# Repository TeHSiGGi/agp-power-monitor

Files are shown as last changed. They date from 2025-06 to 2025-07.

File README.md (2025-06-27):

# AGP Power Monitor

The APM is a monitoring tool to determine the exact power consumption of an AGP Graphics Card.
It measures both power provided by the AGP slot as well as through external power sources via: 

- 6 pin Mini-Fit Jr. from Molex (PCIe Power) 
- 4 Pin AMP Mate-n-Lok 1-480424-0 (mostly known as Molex connector, though it isn't one).

## Hardware

At the heart of APM is a custom AGP Riser card which consists mainly of an STM32F103C8T6 and three INA3221 power monitors. 

It measures the voltages and currents of the AGP slot as well as of external power providers. Additionally there are two alternative inputs which can be used to measure any user-chosen external power rail as long as it is within specification.

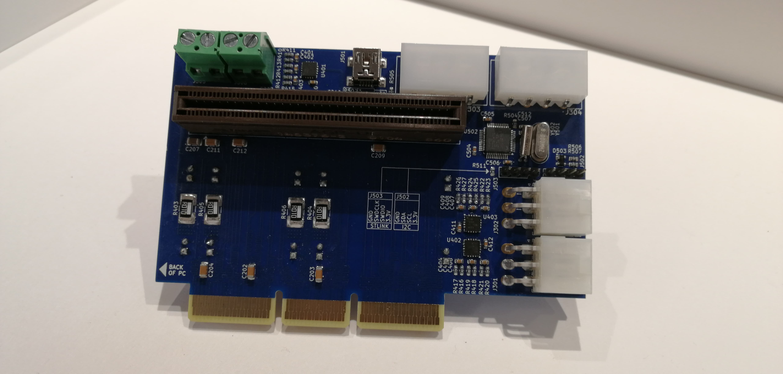
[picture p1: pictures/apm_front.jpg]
APM front

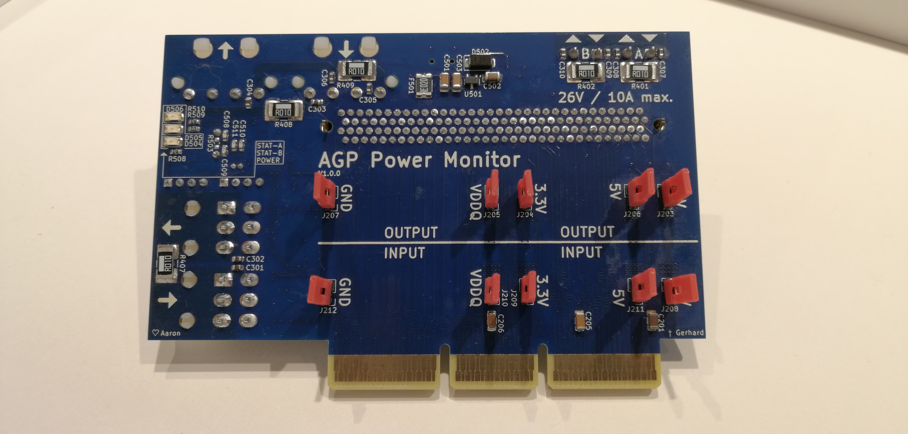
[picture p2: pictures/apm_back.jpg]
APM back


### Power Rails

The following power rails are being measured by the APM.

| Interface | Rail |
| -- | -- |
| AGP slot | 12V |
| AGP slot | 5V |
| AGP slot | 3.3V |
| AGP slot | VDDQ |
| External power | 12V (6Pin) |
| External power | 12V (4Pin) |
| External power | 5V (4Pin) |
| Alternative input | A |
| Alternative input | B |

### Resolution and limits

Each rail can measure:

- Up to 26V of voltage at 8mV steps
- Up to 10A of current at 4mA steps

These resolution values have to be take with a grain of salt, since these are theoretical numbers. The 26V and 10A are the absolute maximum ratings and must not be exceeded at any time.

### Connections:

- 2 keyed AGP gold finger connector
- Universal AGP slot
- Mini-Fit Jr 6 Pin input and output
- Mate-n-Lok 4 Pin input and output
- 2 Screw terminals for alternative channels A and B
- 4 Pin header for additional I2C devices
- 4 Pin header for STlink programming
- USB Mini B interface for connecting to a PC running the monitoring software

## Firmware

The APM uses an STM32F103C8T6 as its main processor. It serves as a USB interface providing fast access to the data provided by the INA3221.

The firmware is built using Platform.io and programmed via the 4 pin header on the board using STlink.

## Software

The monitoring software for APM is written in python and provides the following capabilities:

- Real time monitoring of all power rails (voltage, current, power)
- Automated calculation of minimum, maximum and average values over time of measurement
- Automated calculation of overall power per interface (AGP slot, external power and alternative inputs)
- Automated calculation of total power of all interfaces combined
  
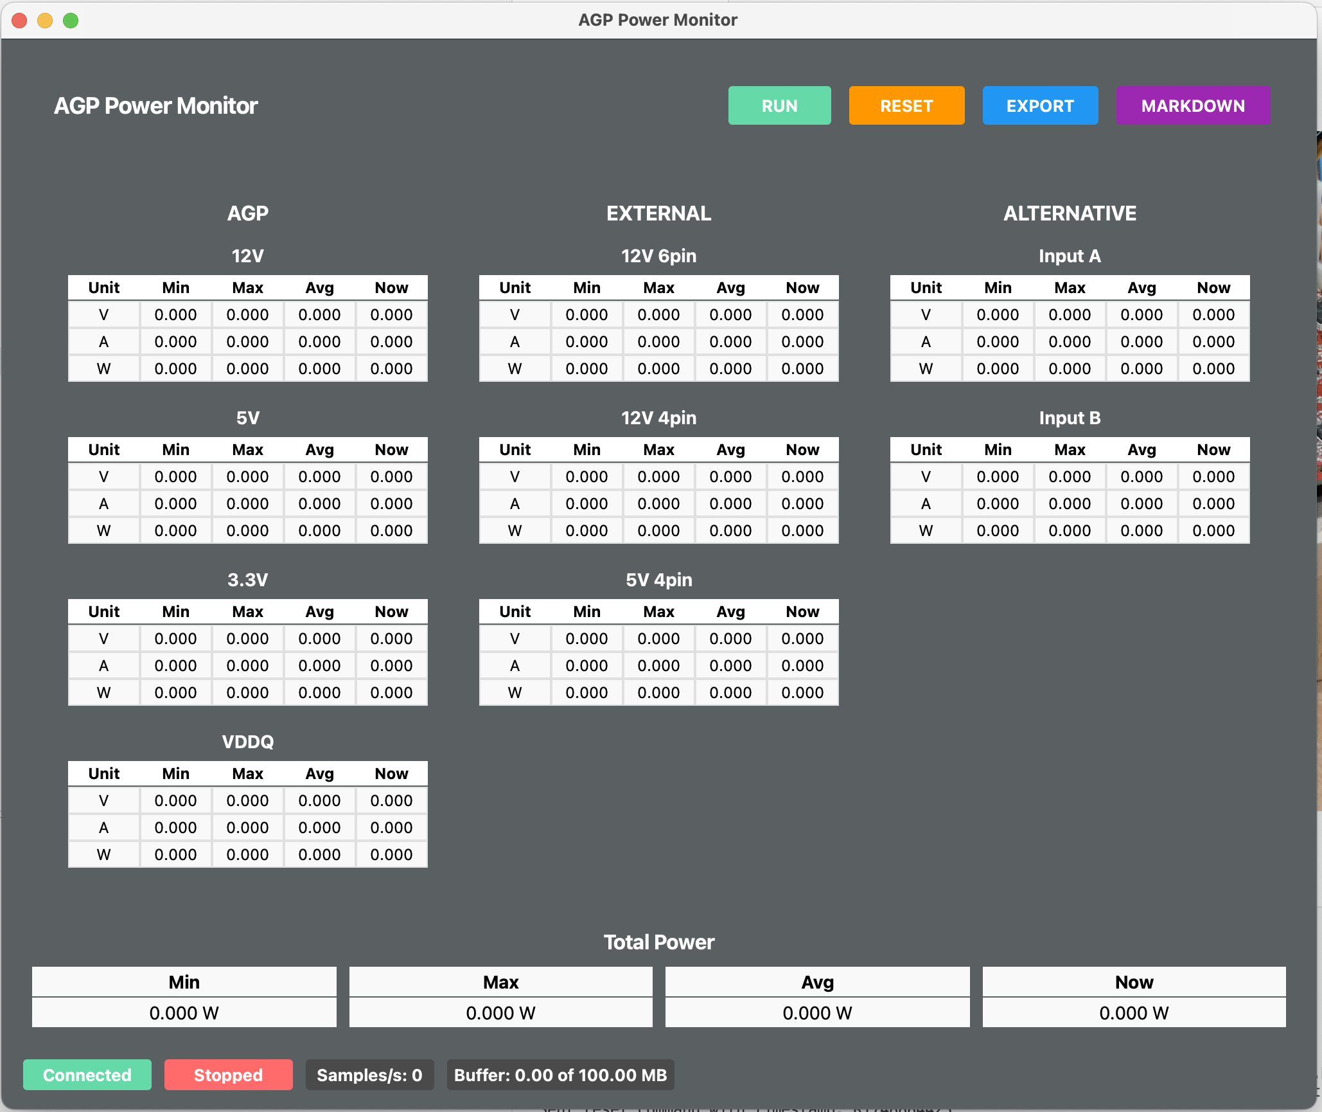
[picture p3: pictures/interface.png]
apm software


## Known issues

- The layout of the AGP gold-fingers is a bit offset in the second and third segment
- CRC checking in the python application not implemented

## Wishlist for the future

- Plotting

## Reference values

To see some values from measured graphics cards, see [reference values](https://tehsiggi.github.io/agp-power-monitor/)

## Disclaimer

This project is provided as is. There is no support or warranty on any parts of it (this includes hardware design, firmware and software). Use it at your own risk.

The author will not be accountable for any damage or harm inflicted.

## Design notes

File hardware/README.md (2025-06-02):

# AGP Power Monitor Hardware

## Project Overview

The AGP Power Monitor is uses a custom AGP riser card to measure and monitor power consumption of AGP cards. It provides real-time voltage and current measurements for the various power rails used by AGP graphics cards, allowing for detailed power analysis and troubleshooting.

## Hardware Design

### Main Components

- **AGP Connectors**: Edge connector for AGP cards and slot connector for motherboard interface
- **Power Measurement**: INA3221 triple-channel power monitors for measuring voltage and current
- **Microcontroller**: STM32F103C8T6 MCU for data processing and USB communication
- **Power Supply**: All logic is powered via the USB input
- **USB Interface**: USB connectivity for data output and device control

### Design Notes

The PCB is a multi-layer design featuring:
- 4 layer with dedicated ground and power planes
- length matches AGP data lines

The USB input is using a polyfuse to prevent damage in case of shortcuts. The 3.3V output of the onboard regulator must not be loaded with more than 250mA. 

You can use the I2C header to connect additional hardware if needed.

The board features pin headers on the backside that can be used for calibration and rail measurement with external measurement equipment.

### Key Features

1. **Inline Power Measurement**: Non-intrusive monitoring between motherboard and graphics card
2. **Multiple Rail Monitoring**: Simultaneous monitoring of AGP power rails (3.3V, 5V, 12V, VDDQ)
3. **External Power Input**: Additional power connectors for supplementary power testing
4. **I²C Expansion**: I²C interface for connecting additional sensors or displays
5. **USB Interface**: Data logging and real-time monitoring via USB

## Connectors and Interfaces

| Connector | Description | Function |
|---|---|---|
| J201 | AGP Edge Connector | Connects to motherboard AGP slot |
| J202 | AGP Slot Connector | Receives AGP graphics card |
| J301/J302 | External Power | 6Pin External 12V power input connectors |
| J303/J304 | External Power | 4Pin 5V/12V power output connector |
| J305/J306 | Alternative Power | Alternative power measurement points |
| J501 | USB Connector | USB data interface |
| J502 | I²C Header | External I²C device connection |

## KiCad Files and Libraries

This project is designed using KiCad 9.0. The directory includes:

- `apm.kicad_pro` - KiCad project file
- `apm.kicad_sch` - Main schematic file
- `apm.kicad_pcb` - PCB layout file
- `lib/` - Custom component libraries:
  - AGP edge connector footprints and symbols
  - AGP slot connector footprints and symbols
  - Power connector footprints and symbols

### Schematic Organization

The schematic is organized into multiple sheets for clarity:

1. **Main Sheet**: Overall system connections
2. **AGP Connectors**: AGP interface connections
3. **External Power**: Power input and conditioning circuits
4. **Sensors**: Power measurement circuits using INA3221
5. **USB Interface**: STM32 microcontroller and USB interface

## Setup Instructions

### Assembly Notes

1. The board requires SMD soldering capabilities (down to 0603 components, QFN packages)
2. Pay special attention to the alignment of AGP connectors
3. The PCB is designed for standard 1.6mm thickness
4. Edge plating is required for the AGP edge connector
5. Beveling (20°) is used during manufacturing

The PCBs have successfully been manufactured at pcbway.com

## BOM

| Part Type | Value/Model | Footprint | Qty | Comment |
|---|---|---|-----|---|
| Capacitors | 4µ7 | 1206 | 2 | Bulk capacitors for 12V rail |
| | 22µ | 1206 | 12 | Bulk capacitors for 3.3V, 5V and VDDQ rail, USB Bus power |
| | 1µ | 0603 | 10 | Bypass capacitors for external and alternative inputs |
| | 100n | 0603 | 16 | Bypass capacitors and filter capacitors for INA3221|
| | 10µ | 1206 | 1 | Bypass capacitor for 3.3V from USB power |
| | 20p | 0603 | 4 | Crystal load capacitors |
| | 10n | 0603 | 1 | Capacitor for reset circuit |
| Resistors | 0R01 | 2816 | 9 | Current shunt resistors |
| | 10 | 0603 | 18 | Pull-up/pull-down resistors |
| | 22 | 0603 | 2 | USB termination resistors |
| | 1M | 0603 | 1 | Crystal load resistor |
| | 10k | 0603 | 1 | Pull-up resistor |
| | 4k7 | 0603 | 1 | Pull-up resistor |
| | 3k3 | 0603 | 3 | Pull-up resistors |
| | 220 | 0603 | 3 | LED current limiting resistors |
| ICs | INA3221 | VQFN | 3 | Triple-channel power monitor |
| | MCP1703AT3302ECB | SOT-23 | 1 | 3.3V voltage regulator |
| | STM32F103C8T6 | LQFP-48 | 1 | 32-bit ARM microcontroller |
| Protection | PRTR5V0U2X | SOT-143 | 2 | USB ESD protection |
| | P4SMAJ5.0A | SMA | 1 | TVS diode |
| | 200mA | 1812 | 1 | Polyfuse |
| Connectors | AGP Edge Connector | edge_universal | 1 | Motherboard interface |
| | 145376-2 | 145376-2 AMP | 1 | AGP card slot |
| | 12V/3.3V/VDDQ/5V/GND PROBE | Pin Header 2 Pin 2.54mm | 10 | Test points |
| | 39301060 | Molex_Mini-Fit_Jr_5569-06A2_2x03_P4.20mm_Horizontal | 2 | 6-pin power connectors |
| | 641737-1 | 641737-1 | 2 | 4-pin power connectors |
| | Screw_Terminal_01x02 | 5.08mm Horizontal | 2 | Alternative power input |
| | USB_B_Mini | Wuerth 65100516121 | 1 | USB interface |
| | I2C/STLink Headers | PinHeader 4 Pin 2.54mm | 2 | Expansion/Programming headers |
| Indicators | LED | 1206 | 3 | Status indicators |
| Crystals | 8MHz | HC49l | 1 | Main MCU oscillator |
| | 32.768kHz | DS10 | 1 | RTC oscillator |

## Revision History

- Rev 1.0.0: Initial hardware design

## Disclaimer

This project is provided as is. There is no support or warranty on any parts of it (this includes hardware design, firmware and software). Use it at your own risk.

The author will not be accountable for any damage or harm inflicted.

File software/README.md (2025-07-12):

# AGP Power Monitor

A Qt-based Python application with a tabbed interface designed for monitoring power.

## Features

- Real time data display of all rails
- Average, Maximum and Minimum calculation
- Export of data into CSV
- Copy of power statistics as markdown

## Setup and starting

### Linux / MacOS

Use the `setup.sh` shell script:

`setup.sh install` to install all required libraries.

`setup.sh start` to start the application

`setup.sh start /dev/ttyACM0` adds the serial interface to be used

### Windows

Use the `setup.bat` batch script:

`.\setup.bat install` to install all required libraries

`.\setup.bat start` to start the application

`.\setup.bat start COM4` adds the serial interface to be used

## Configuration

You can either modify the `config.yaml` file to meet your setup or provide overrides when running the program.

Allowed flags are:

- `port` - Serial port to connect to (e.g., `/dev/ttyACM0`, `COM3`)
- `--correction-factor` or `-c` - Current correction factor
- `--debug` or `-d` - Enable debug output
- `--baudrate` or `-b` - Serial baudrate
- `--config` - Path to a custom config.yaml file

Example:

```sh
./setup.sh start /dev/ttyUSB0 --debug --baudrate 9600
```

## Configuration File Structure

The `config.yaml` file contains the following sections:

```yaml
serial:
  port: /dev/ttyACM0      # Serial port to connect to
  baudrate: 115200        # Serial port baudrate
  timeout: 1.0            # Read timeout in seconds

measurement:
  uiUpdateInterval: 100   # Update interval for UI values in milliseconds
  currentCorrectionFactor: 1.0275  # Factor to adjust current readings
  maxBufferSizeMB: 100.0  # Maximum buffer size in megabytes

debugLog: false           # Enable/disable debug logging
```

## Serial Data Protocol

The application communicates with hardware devices using a custom serial protocol. Each data package contains:

- Epoch timestamp (32-bit unsigned integer)
- Sample ID in current time (8-bit unsigned integer)
- Bus voltages for 9 rails (16-bit unsigned integers, direct register values)
- Shunt voltages for 9 rails (16-bit signed integers, direct register values)
- CRC-16 (CCITT) checksum for data validation
- 3-byte end marker (FF0033)

## Disclaimer

This project is provided as is. There is no support or warranty on any parts of it (this includes hardware design, firmware and software). Use it at your own risk.

The author will not be accountable for any damage or harm inflicted.

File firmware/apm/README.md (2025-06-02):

# AGP Power Monitor Firmware

This firmware runs on an STM32 microcontroller to monitor power consumption of an AGP graphics card and associated power rails.

## Overview

The AGP Power Monitor provides accurate measurement of voltage and current across multiple power rails:
- AGP slot power (3.3V, 5V, 12V)
- External power connectors (4-pin, 6-pin)
- Alternative power channels

Data is collected at high frequency, processed, and streamed over USB serial connection for analysis.

## Hardware

- **Microcontroller**: STM32F103C8T6
- **Power Measurement**: Three INA3221 triple-channel power monitors
- **Status Indicators**: Two LEDs for operational status
- **Real-Time Clock**: Internal STM32 RTC for precise timestamping

### Monitored Power Rails

1. **INA3221 #1 (0x43)**:
   - Channel 1: Alternative channel A
   - Channel 2: Alternative channel B
   - Channel 3: 12V AGP

2. **INA3221 #2 (0x42)**:
   - Channel 1: 3.3V AGP
   - Channel 2: 5V AGP
   - Channel 3: VDDQ AGP

3. **INA3221 #3 (0x40)**:
   - Channel 1: 12V 6-pin connector
   - Channel 2: 5V 4-pin connector
   - Channel 3: 12V 4-pin connector

## Setup and Installation

### Prerequisites

- [PlatformIO](https://platformio.org/) (with VSCode or CLI)
- USB connection to the device
- STLink programmer

### Building and Flashing

1. Clone this repository
2. Open the project folder in VSCode with PlatformIO extension installed
3. Connect the STM32 board via USB and STLink
4. Build and upload using platform.io

## Serial Command Interface

Connect to the device using a serial monitor at 115200 baud (although baud rate doesn't matter over USB CDC).

### Available Commands

- **Set RTC**: `R<unix_timestamp>`  
  Sets the real-time clock with a Unix timestamp.
  Example: `R1658358000` (sets RTC to July 21, 2022 00:00:00 UTC)

- **Start Sampling**: `S`  
  Begins continuous power sampling and data output.
  Note: Requires RTC to be configured first.

- **Stop Sampling**: `P`  
  Stops the power sampling.

## Status LED Indicators

- **STAT_A LED**: Blinks when RTC is not configured, solid ON when RTC is set
- **STAT_B LED**: Toggles with each sampling cycle to indicate activity

## Data Output Format

When sampling, data is output continuously in binary format:

| Bytes | Description |
|---|---|
| 0-3 | Unix timestamp (32-bit, big-endian) |
| 4 | Sample count (0-255 for each second) |
| 5-40  | Bus voltage readings (9 × 16-bit values) |
| 41-76 | Shunt voltage readings (9 × 16-bit values) |
| 77-78 | CRC-16 (CCITT) checksum |
| 79-81 | Packet end marker (FF0033) |

The values for the voltages are direct register values from the INA3221.

### Converting Values

- **Bus Voltage**: Raw value × LSB (0.008V)
- **Shunt Voltage**: Raw value × LSB (0.00004V)
- **Current**: Shunt voltage ÷ shunt resistor value

## Troubleshooting

- **No data output**: Ensure RTC is configured and sampling is started
- **Incorrect readings**: Check connections on INA3221 chips

## Disclaimer

This project is provided as is. There is no support or warranty on any parts of it (this includes hardware design, firmware and software). Use it at your own risk.

The author will not be accountable for any damage or harm inflicted.

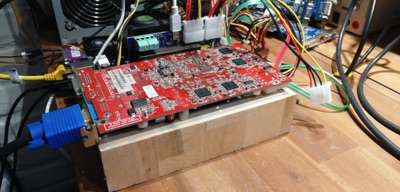
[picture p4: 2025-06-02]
pictures/apm_in_use_small.jpeg

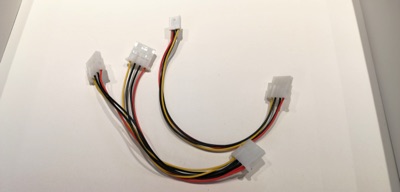
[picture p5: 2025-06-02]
pictures/apm_dongles_small.jpeg

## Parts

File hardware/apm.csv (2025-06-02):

Reference | Value | Footprint | Datasheet | Qty | DNP
C201,C207 | 4µ7 | Capacitor_SMD:C_1206_3216Metric | ~ | 2
C202,C203,C204,C205,C206,C208,C209,C210,C211,C212,C501,C502 | 22µ | Capacitor_SMD:C_1206_3216Metric | ~ | 12
C301,C302,C303,C304,C305,C306,C307,C308,C309,C310 | 1µ | Capacitor_SMD:C_0603_1608Metric | ~ | 10
C401,C402,C403,C404,C405,C406,C407,C408,C409,C410,C411,C412,C504,C505,C506,C507 | 100n | Capacitor_SMD:C_0603_1608Metric | ~ | 16
C503 | 10µ | Capacitor_SMD:C_1206_3216Metric | ~ | 1
C508,C509,C510,C511 | 20p | Capacitor_SMD:C_0603_1608Metric | ~ | 4
C512 | 10n | Capacitor_SMD:C_0603_1608Metric | ~ | 1
D501,D503 | PRTR5V0U2X | Package_TO_SOT_SMD:SOT-143 | https://assets.nexperia.com/documents/data-sheet/PRTR5V0U2X.pdf | 2
D502 | P4SMAJ5.0A | Diode_SMD:D_SMA | https://www.littelfuse.com/media?itemid=75e32973-b177-4ee3-a0ff-cedaf1abdb93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 | 1
D504,D505,D506 | LED | LED_SMD:LED_1206_3216Metric | ~ | 3
F501 | 200mA | Fuse:Fuse_1812_4532Metric | ~ | 1
J201 | ~ | agp-edge:edge_universal |  | 1
J202 | 145376-2 | agp-slot:Conn_AMP_1MM_STD_EDGE_132_POS_145376-2 | https://www.te.com/commerce/DocumentDelivery/DDEController?Action=srchrtrv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 | 1
J203,J208 | 12V_PROBE | Connector_PinHeader_2.54mm:PinHeader_1x02_P2.54mm_Vertical | ~ | 2
J204,J209 | 3.3V_PROBE | Connector_PinHeader_2.54mm:PinHeader_1x02_P2.54mm_Vertical | ~ | 2
J205,J210 | VDDQ_PROBE | Connector_PinHeader_2.54mm:PinHeader_1x02_P2.54mm_Vertical | ~ | 2
J206,J211 | 5V_PROBE | Connector_PinHeader_2.54mm:PinHeader_1x02_P2.54mm_Vertical | ~ | 2
J207,J212 | GND_PROBE | Connector_PinHeader_2.54mm:PinHeader_1x02_P2.54mm_Vertical | ~ | 2
J301,J302 | 39301060 | Connector_Molex:Molex_Mini-Fit_Jr_5569-06A2_2x03_P4.20mm_Horizontal | ~ | 2
J303,J304 | 641737-1 | 641737-1:641737-1 | https://www.te.com/commerce/DocumentDelivery/DDEController?Action=srchrtrv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 | 2
J305,J306 | Screw_Terminal_01x02 | TerminalBlock_RND:TerminalBlock_RND_205-00232_1x02_P5.08mm_Horizontal | ~ | 2
J501 | USB_B_Mini | Connector_USB:USB_Mini-B_Wuerth_65100516121_Horizontal | ~ | 1
J502 | I2C | Connector_PinHeader_2.54mm:PinHeader_1x04_P2.54mm_Vertical | ~ | 1
J503 | STLink | Connector_PinHeader_2.54mm:PinHeader_1x04_P2.54mm_Vertical | ~ | 1
R401,R402,R403,R404,R405,R406,R407,R408,R409 | 0R01 | Resistor_SMD:R_2816_7142Metric | ~ | 9
R410,R411,R412,R413,R414,R415,R416,R417,R418,R419,R420,R421,R422,R423,R424,R425,R426,R427 | 10 | Resistor_SMD:R_0603_1608Metric | ~ | 18
R501,R502 | 22 | Resistor_SMD:R_0603_1608Metric | ~ | 2
R503 | 1M | Resistor_SMD:R_0603_1608Metric | ~ | 1
R504 | 10k | Resistor_SMD:R_0603_1608Metric | ~ | 1
R505 | 4k7 | Resistor_SMD:R_0603_1608Metric | ~ | 1
R506,R507,R511 | 3k3 | Resistor_SMD:R_0603_1608Metric | ~ | 3
R508,R509,R510 | 220 | Resistor_SMD:R_0603_1608Metric | ~ | 3
U401,U402,U403 | INA3221 | Package_DFN_QFN:Texas_RGV0016A_VQFN-16-1EP_4x4mm_P0.65mm_EP2.1x2.1mm | http://www.ti.com/lit/ds/symlink/ina3221.pdf | 3
U501 | MCP1703Ax-330xxTT | Package_TO_SOT_SMD:SOT-23 | http://ww1.microchip.com/downloads/en/DeviceDoc/20005122B.pdf | 1
U502 | STM32F103C6Tx | Package_QFP:LQFP-48_7x7mm_P0.5mm | https://www.st.com/resource/en/datasheet/stm32f103c6.pdf | 1
Y501 | 8MHz | Crystal:Crystal_HC49-U_Vertical | ~ | 1
Y502 | 32.768kHz | Crystal:Crystal_DS10_D1.0mm_L4.3mm_Horizontal | ~ | 1

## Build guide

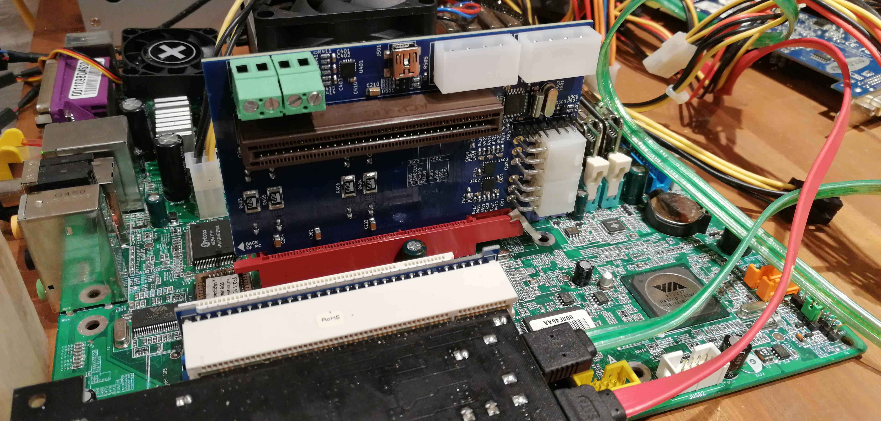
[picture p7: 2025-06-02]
pictures/apm_installed.jpg

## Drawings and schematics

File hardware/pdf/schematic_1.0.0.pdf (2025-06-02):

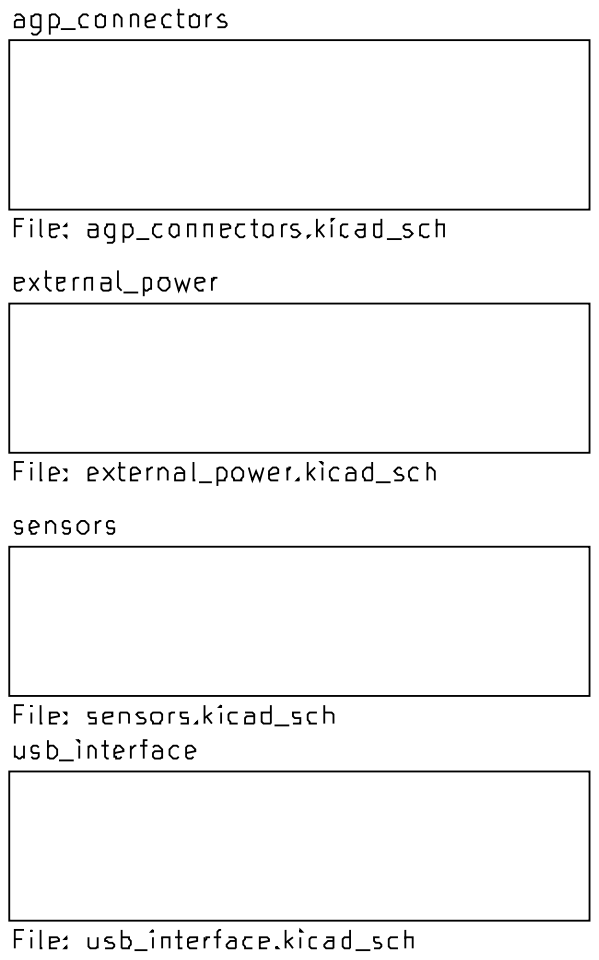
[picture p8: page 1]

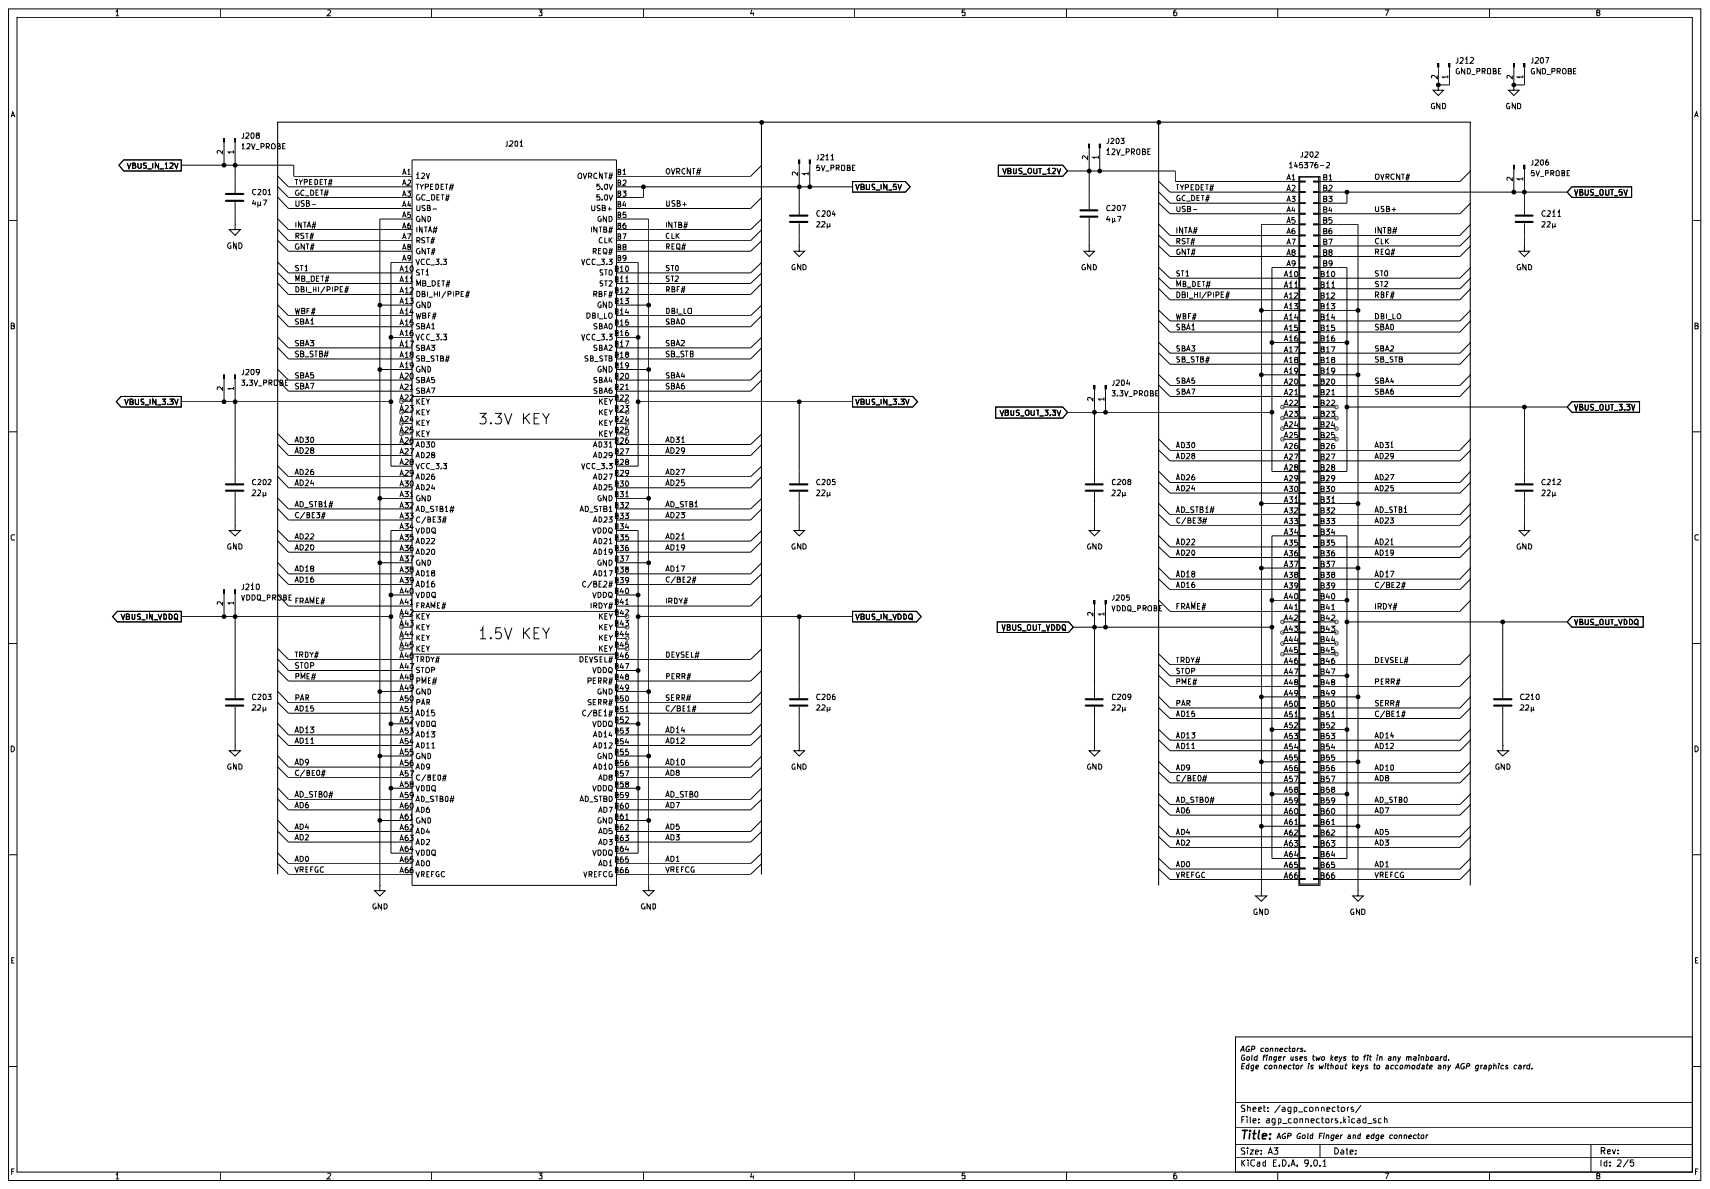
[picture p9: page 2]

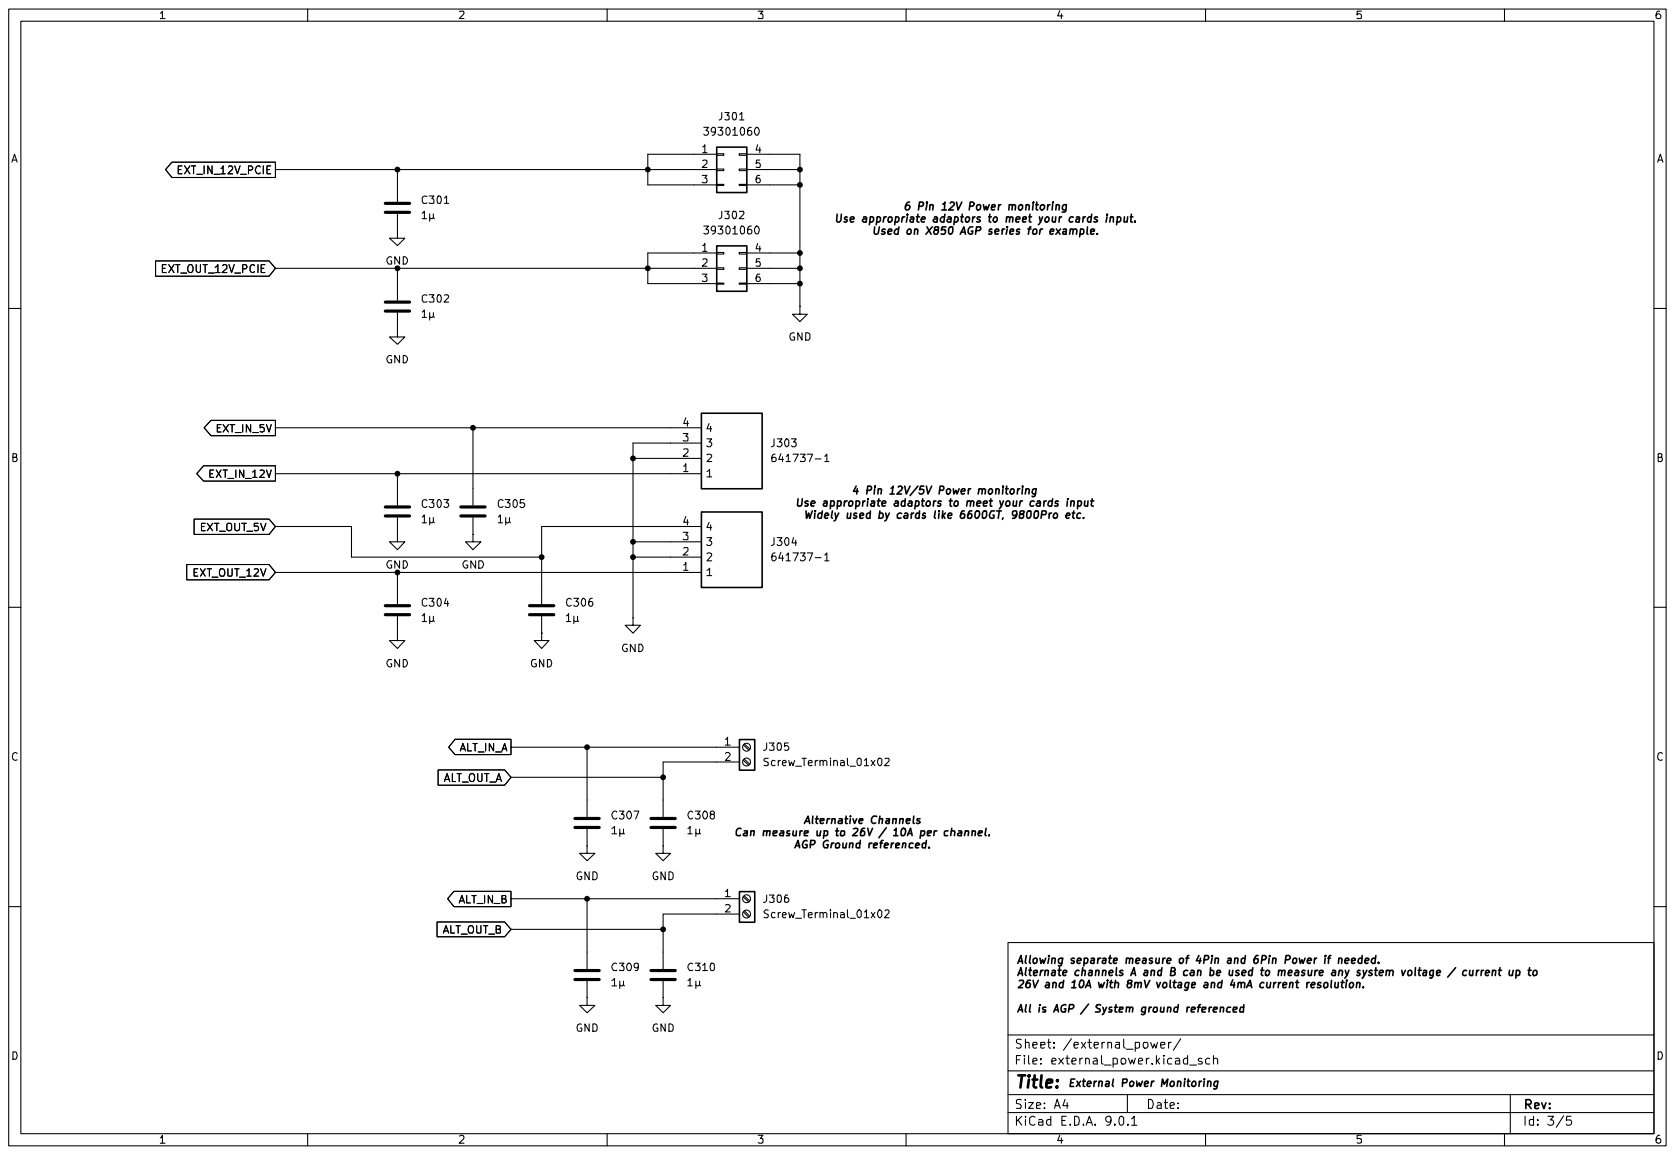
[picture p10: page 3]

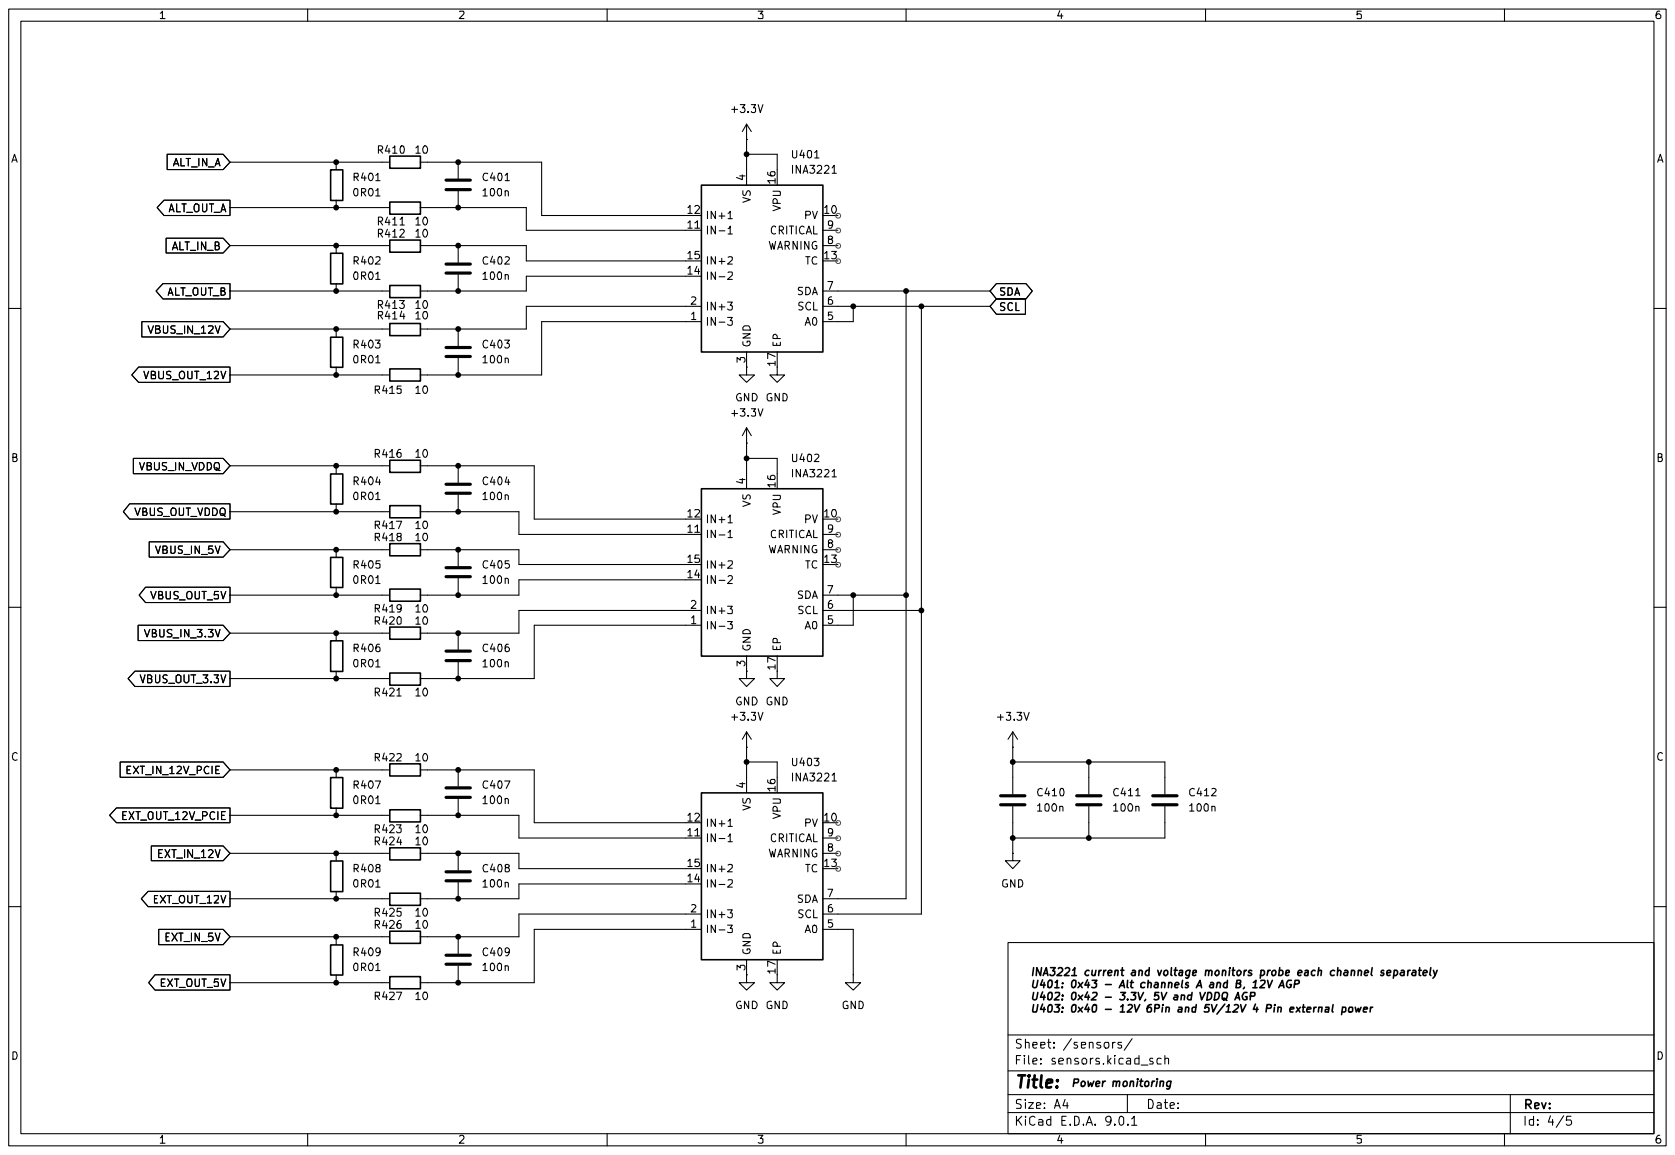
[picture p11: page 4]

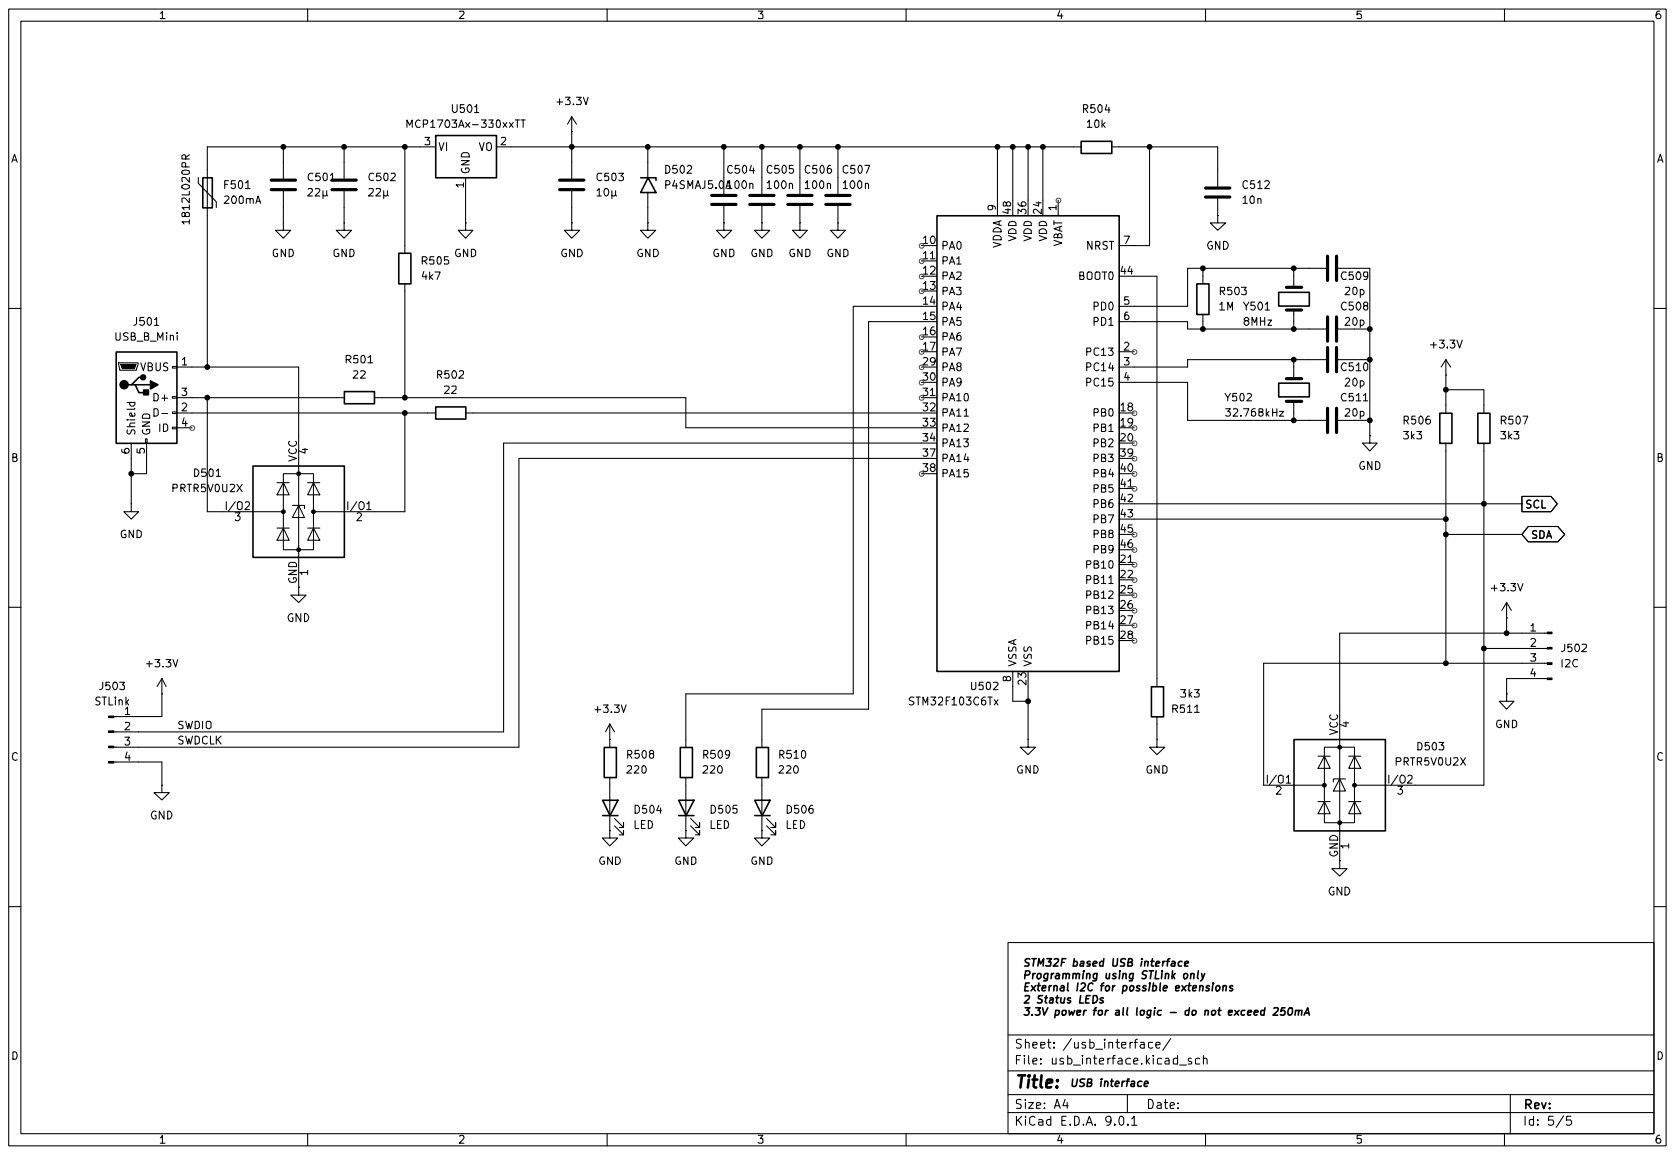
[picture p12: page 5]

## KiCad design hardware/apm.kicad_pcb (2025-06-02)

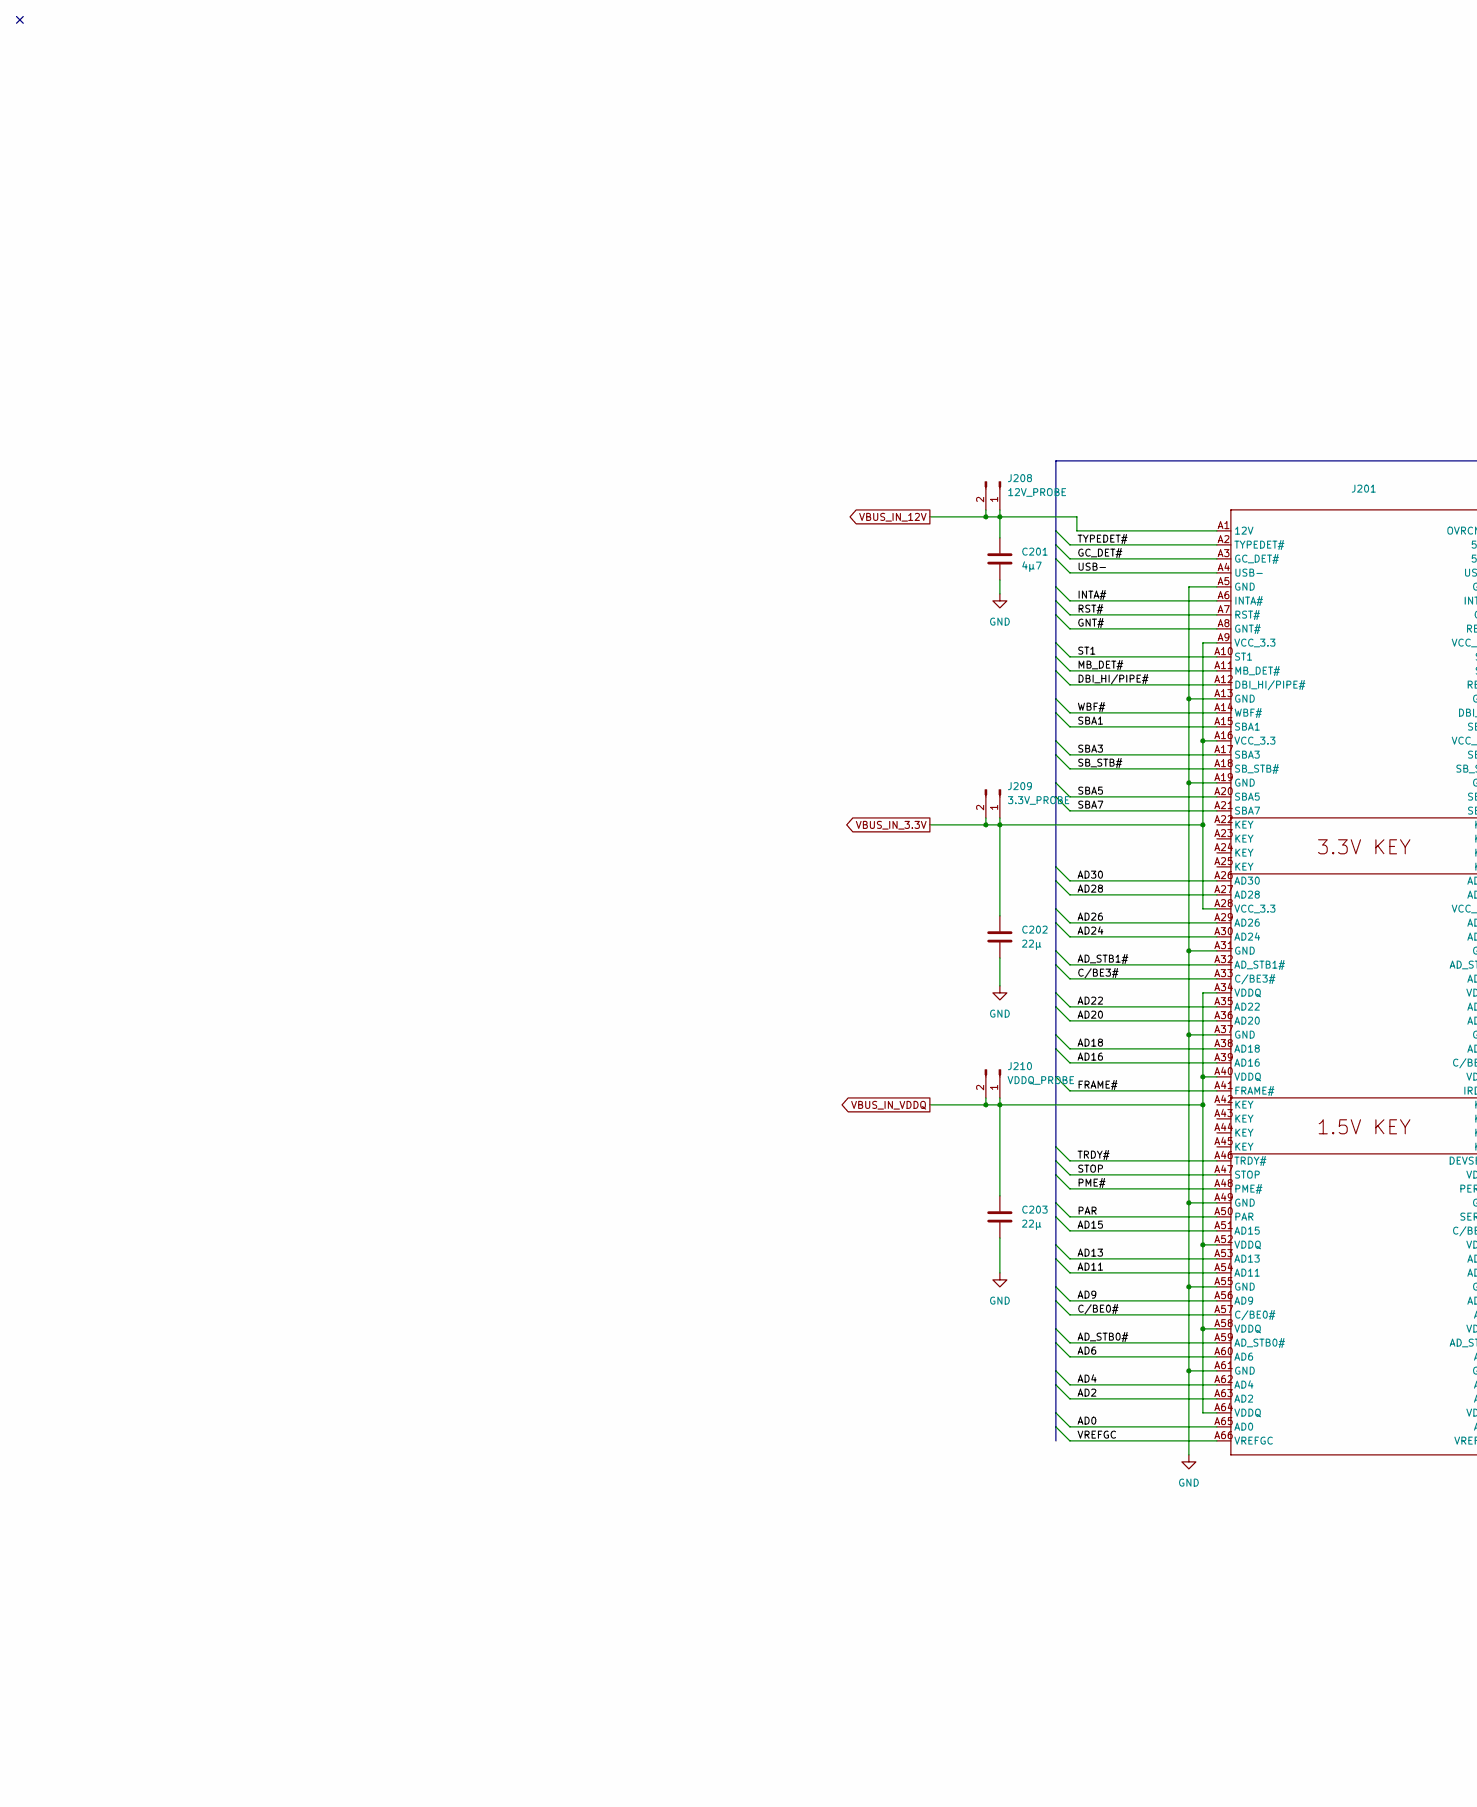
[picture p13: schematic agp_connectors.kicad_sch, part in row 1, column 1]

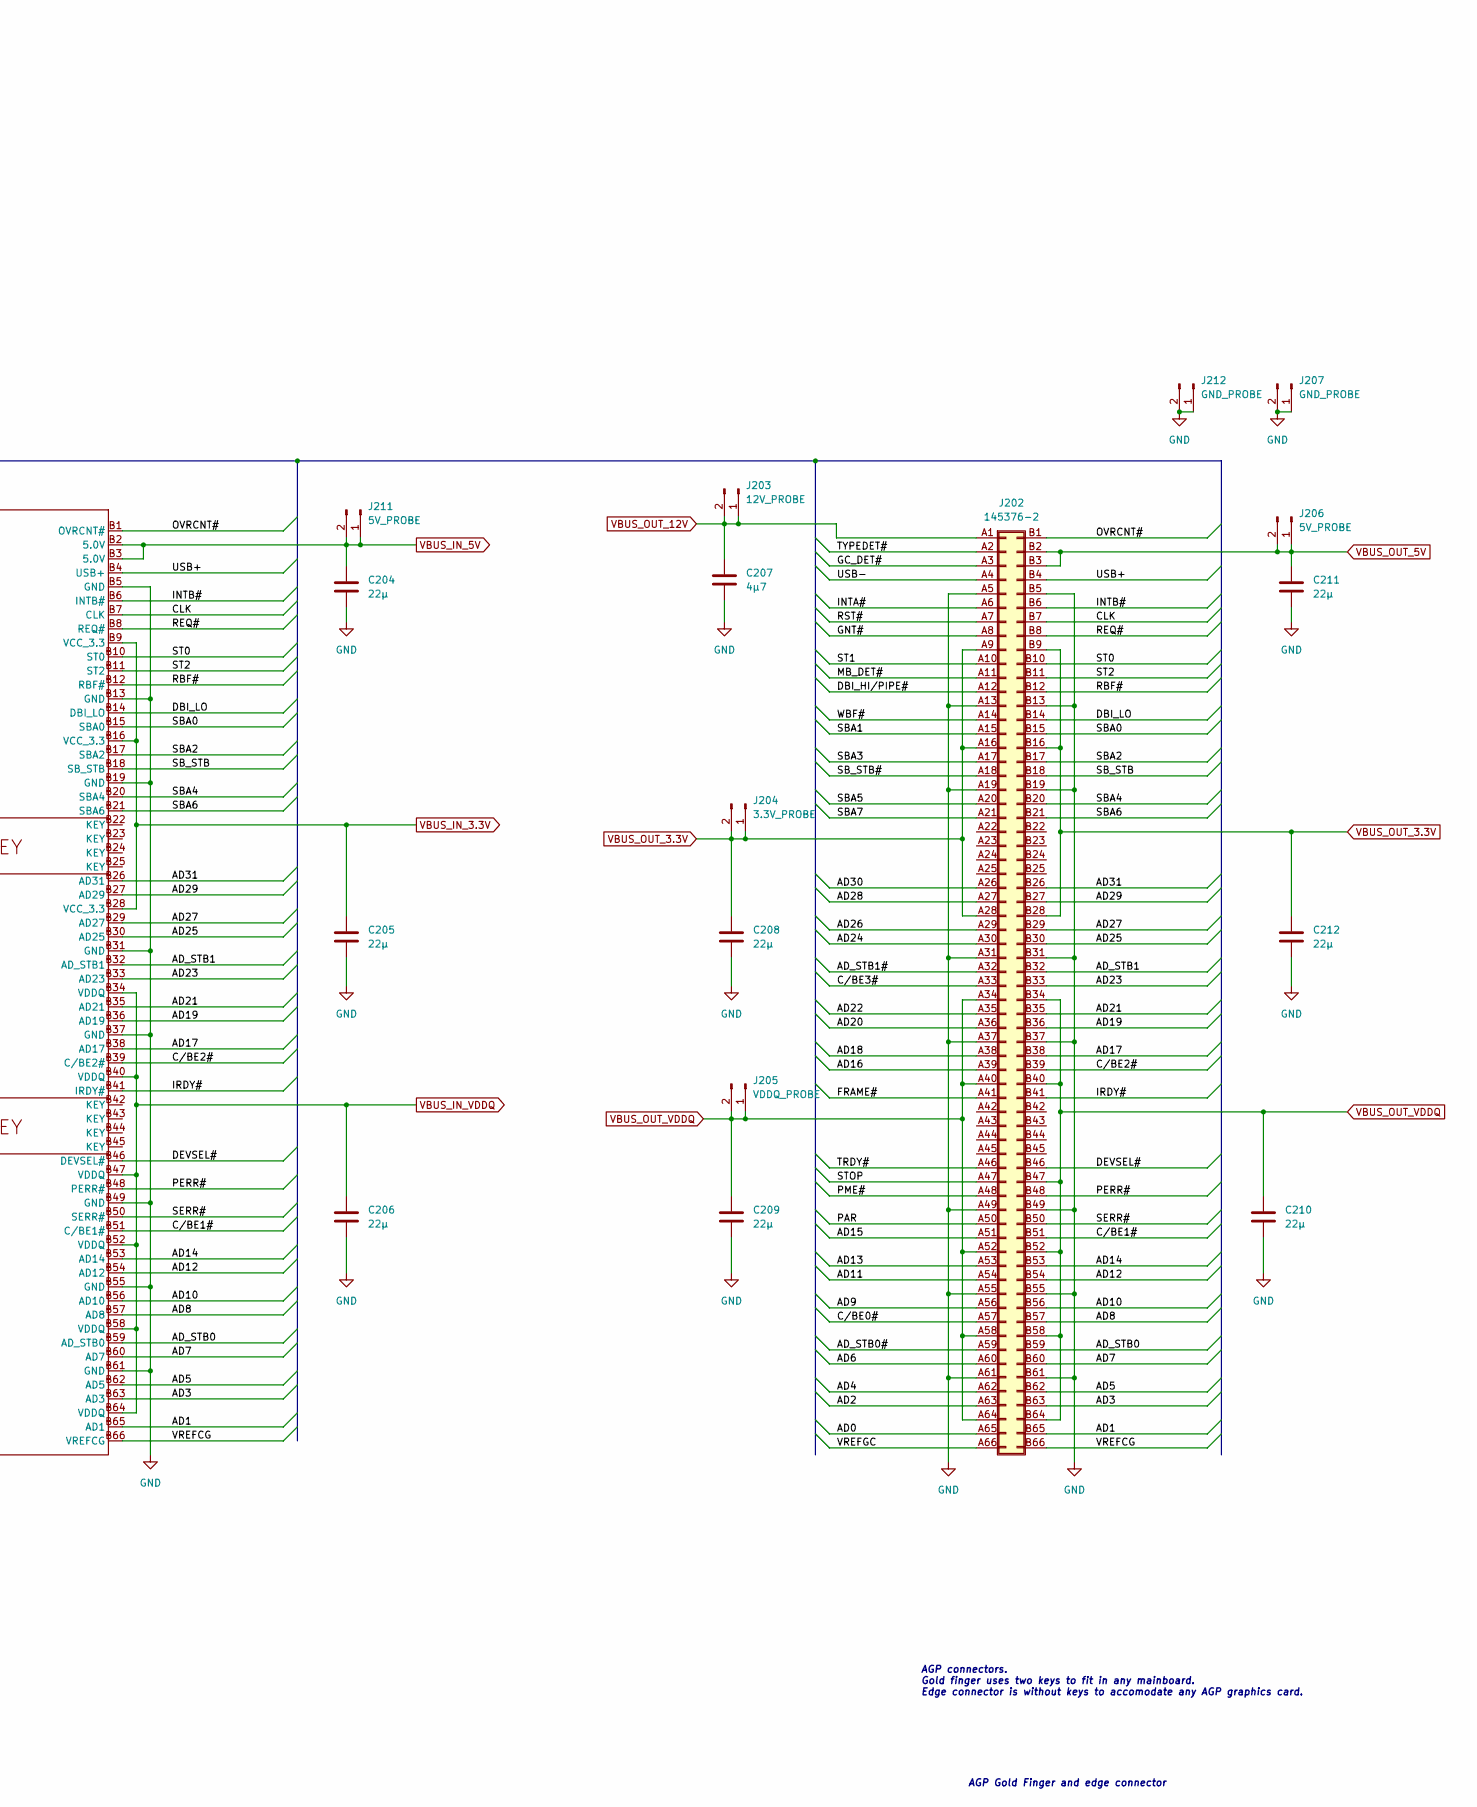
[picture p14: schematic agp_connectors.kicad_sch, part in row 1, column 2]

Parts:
C201, C207: 4µ7; C_1206_3216Metric
C202, C203, C204, C205, C206, C208, C209, C210, C211, C212: 22µ; C_1206_3216Metric
J201: edge_universal
J202: 145376-2; Conn_AMP_1MM_STD_EDGE_132_POS_145376-2
J203, J208: 12V_PROBE; PinHeader_1x02_P2.54mm_Vertical
J204, J209: 3.3V_PROBE; PinHeader_1x02_P2.54mm_Vertical
J205, J210: VDDQ_PROBE; PinHeader_1x02_P2.54mm_Vertical
J206, J211: 5V_PROBE; PinHeader_1x02_P2.54mm_Vertical
J207, J212: GND_PROBE; PinHeader_1x02_P2.54mm_Vertical

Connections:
/agp_connectors/AD0: J201.A65 (AD0), J202.A65 (65)
/agp_connectors/AD1: J201.B65 (AD1), J202.B65 (131)
/agp_connectors/AD2: J201.A63 (AD2), J202.A63 (63)
/agp_connectors/AD3: J201.B63 (AD3), J202.B63 (129)
/agp_connectors/AD4: J201.A62 (AD4), J202.A62 (62)
/agp_connectors/AD5: J201.B62 (AD5), J202.B62 (128)
/agp_connectors/AD6: J201.A60 (AD6), J202.A60 (60)
/agp_connectors/AD7: J201.B60 (AD7), J202.B60 (126)
/agp_connectors/AD8: J201.B57 (AD8), J202.B57 (123)
/agp_connectors/AD9: J201.A56 (AD9), J202.A56 (56)
/agp_connectors/AD10: J201.B56 (AD10), J202.B56 (122)
/agp_connectors/AD11: J201.A54 (AD11), J202.A54 (54)
/agp_connectors/AD12: J201.B54 (AD12), J202.B54 (120)
/agp_connectors/AD13: J201.A53 (AD13), J202.A53 (53)
/agp_connectors/AD14: J201.B53 (AD14), J202.B53 (119)
/agp_connectors/AD15: J201.A51 (AD15), J202.A51 (51)
/agp_connectors/AD16: J201.A39 (AD16), J202.A39 (39)
/agp_connectors/AD17: J201.B38 (AD17), J202.B38 (104)
/agp_connectors/AD18: J201.A38 (AD18), J202.A38 (38)
/agp_connectors/AD19: J201.B36 (AD19), J202.B36 (102)
/agp_connectors/AD20: J201.A36 (AD20), J202.A36 (36)
/agp_connectors/AD21: J201.B35 (AD21), J202.B35 (101)
/agp_connectors/AD22: J201.A35 (AD22), J202.A35 (35)
/agp_connectors/AD23: J201.B33 (AD23), J202.B33 (99)
/agp_connectors/AD24: J201.A30 (AD24), J202.A30 (30)
/agp_connectors/AD25: J201.B30 (AD25), J202.B30 (96)
/agp_connectors/AD26: J201.A29 (AD26), J202.A29 (29)
/agp_connectors/AD27: J201.B29 (AD27), J202.B29 (95)
/agp_connectors/AD28: J201.A27 (AD28), J202.A27 (27)
/agp_connectors/AD29: J201.B27 (AD29), J202.B27 (93)
/agp_connectors/AD30: J201.A26 (AD30), J202.A26 (26)
/agp_connectors/AD31: J201.B26 (AD31), J202.B26 (92)
/agp_connectors/AD_STB0: J201.B59 (AD_STB0), J202.B59 (125)
/agp_connectors/AD_STB0#: J201.A59 (AD_STB0#), J202.A59 (59)
/agp_connectors/AD_STB1: J201.B32 (AD_STB1), J202.B32 (98)
/agp_connectors/AD_STB1#: J201.A32 (AD_STB1#), J202.A32 (32)
/agp_connectors/CLK: J201.B7 (CLK), J202.B7 (73)
/agp_connectors/C/BE0#: J201.A57 (C/BE0#), J202.A57 (57)
/agp_connectors/C/BE1#: J201.B51 (C/BE1#), J202.B51 (117)
/agp_connectors/C/BE2#: J201.B39 (C/BE2#), J202.B39 (105)
/agp_connectors/C/BE3#: J201.A33 (C/BE3#), J202.A33 (33)
/agp_connectors/DBI_HI/PIPE#: J201.A12 (DBI_HI/PIPE#), J202.A12 (12)
/agp_connectors/DBI_LO: J201.B14 (DBI_LO), J202.B14 (80)
/agp_connectors/DEVSEL#: J201.B46 (DEVSEL#), J202.B46 (112)
/agp_connectors/FRAME#: J201.A41 (FRAME#), J202.A41 (41)
/agp_connectors/GC_DET#: J201.A3 (GC_DET#), J202.A3 (3)
/agp_connectors/GNT#: J201.A8 (GNT#), J202.A8 (8)
/agp_connectors/INTA#: J201.A6 (INTA#), J202.A6 (6)
/agp_connectors/INTB#: J201.B6 (INTB#), J202.B6 (72)
/agp_connectors/IRDY#: J201.B41 (IRDY#), J202.B41 (107)
/agp_connectors/MB_DET#: J201.A11 (MB_DET#), J202.A11 (11)
/agp_connectors/OVRCNT#: J201.B1 (OVRCNT#), J202.B1 (67)
/agp_connectors/PAR: J201.A50 (PAR), J202.A50 (50)
/agp_connectors/PERR#: J201.B48 (PERR#), J202.B48 (114)
/agp_connectors/PME#: J201.A48 (PME#), J202.A48 (48)
/agp_connectors/RBF#: J201.B12 (RBF#), J202.B12 (78)
/agp_connectors/REQ#: J201.B8 (REQ#), J202.B8 (74)
/agp_connectors/RST#: J201.A7 (RST#), J202.A7 (7)
/agp_connectors/SBA0: J201.B15 (SBA0), J202.B15 (81)
/agp_connectors/SBA1: J201.A15 (SBA1), J202.A15 (15)
/agp_connectors/SBA2: J201.B17 (SBA2), J202.B17 (83)
/agp_connectors/SBA3: J201.A17 (SBA3), J202.A17 (17)
/agp_connectors/SBA4: J201.B20 (SBA4), J202.B20 (86)
/agp_connectors/SBA5: J201.A20 (SBA5), J202.A20 (20)
/agp_connectors/SBA6: J201.B21 (SBA6), J202.B21 (87)
/agp_connectors/SBA7: J201.A21 (SBA7), J202.A21 (21)
/agp_connectors/SB_STB: J201.B18 (SB_STB), J202.B18 (84)
/agp_connectors/SB_STB#: J201.A18 (SB_STB#), J202.A18 (18)
/agp_connectors/SERR#: J201.B50 (SERR#), J202.B50 (116)
/agp_connectors/ST0: J201.B10 (ST0), J202.B10 (76)
/agp_connectors/ST1: J201.A10 (ST1), J202.A10 (10)
/agp_connectors/ST2: J201.B11 (ST2), J202.B11 (77)
/agp_connectors/STOP: J201.A47 (STOP), J202.A47 (47)
/agp_connectors/TRDY#: J201.A46 (TRDY#), J202.A46 (46)
/agp_connectors/TYPEDET#: J201.A2 (TYPEDET#), J202.A2 (2)
/agp_connectors/USB+: J201.B4 (USB+), J202.B4 (70)
/agp_connectors/USB-: J201.A4 (USB-), J202.A4 (4)
/agp_connectors/VREFCG: J201.B66 (VREFCG), J202.B66 (132)
/agp_connectors/VREFGC: J201.A66 (VREFGC), J202.A66 (66)
/agp_connectors/WBF#: J201.A14 (WBF#), J202.A14 (14)
GND: C201.2, C202.2, C203.2, C204.2, C205.2, C206.2, C207.2, C208.2, C209.2, C210.2, C211.2, C212.2, J201.A5 (GND), J201.A13 (GND), J201.A19 (GND), J201.A31 (GND), J201.A37 (GND), J201.A49 (GND), J201.A55 (GND), J201.A61 (GND), J201.B5 (GND), J201.B13 (GND), J201.B19 (GND), J201.B31 (GND), J201.B37 (GND), J201.B49 (GND), J201.B55 (GND), J201.B61 (GND), J202.A5 (5), J202.A13 (13), J202.A19 (19), J202.A31 (31), J202.A37 (37), J202.A49 (49), J202.A55 (55), J202.A61 (61), J202.B5 (71), J202.B13 (79), J202.B19 (85), J202.B31 (97), J202.B37 (103), J202.B49 (115), J202.B55 (121), J202.B61 (127), J207.1, J207.2, J212.1, J212.2; also elsewhere on the board
VBUS_IN_3.3V: C202.1, C205.1, J201.A9 (VCC_3.3), J201.A16 (VCC_3.3), J201.A28 (VCC_3.3), J201.B9 (VCC_3.3), J201.B16 (VCC_3.3), J201.B28 (VCC_3.3), J209.1, J209.2; also elsewhere on the board
VBUS_IN_5V: C204.1, J201.B2 (5.0V), J201.B3 (5.0V), J211.1, J211.2; also elsewhere on the board
VBUS_IN_12V: C201.1, J201.A1 (12V), J208.1, J208.2; also elsewhere on the board
VBUS_IN_VDDQ: C203.1, C206.1, J201.A34 (VDDQ), J201.A40 (VDDQ), J201.A52 (VDDQ), J201.A58 (VDDQ), J201.A64 (VDDQ), J201.B34 (VDDQ), J201.B40 (VDDQ), J201.B47 (VDDQ), J201.B52 (VDDQ), J201.B58 (VDDQ), J201.B64 (VDDQ), J210.1, J210.2; also elsewhere on the board
VBUS_OUT_3.3V: C208.1, C212.1, J202.A9 (9), J202.A16 (16), J202.A28 (28), J202.B9 (75), J202.B16 (82), J202.B28 (94), J204.1, J204.2; also elsewhere on the board
VBUS_OUT_5V: C211.1, J202.B2 (68), J202.B3 (69), J206.1, J206.2; also elsewhere on the board
VBUS_OUT_12V: C207.1, J202.A1 (1), J203.1, J203.2; also elsewhere on the board
VBUS_OUT_VDDQ: C209.1, C210.1, J202.A34 (34), J202.A40 (40), J202.A52 (52), J202.A58 (58), J202.A64 (64), J202.B34 (100), J202.B40 (106), J202.B47 (113), J202.B52 (118), J202.B58 (124), J202.B64 (130), J205.1, J205.2; also elsewhere on the board

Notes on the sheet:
AGP connectors. Gold finger uses two keys to fit in any mainboard. Edge connector is without keys to accomodate any AGP graphics card.
AGP Gold Finger and edge connector

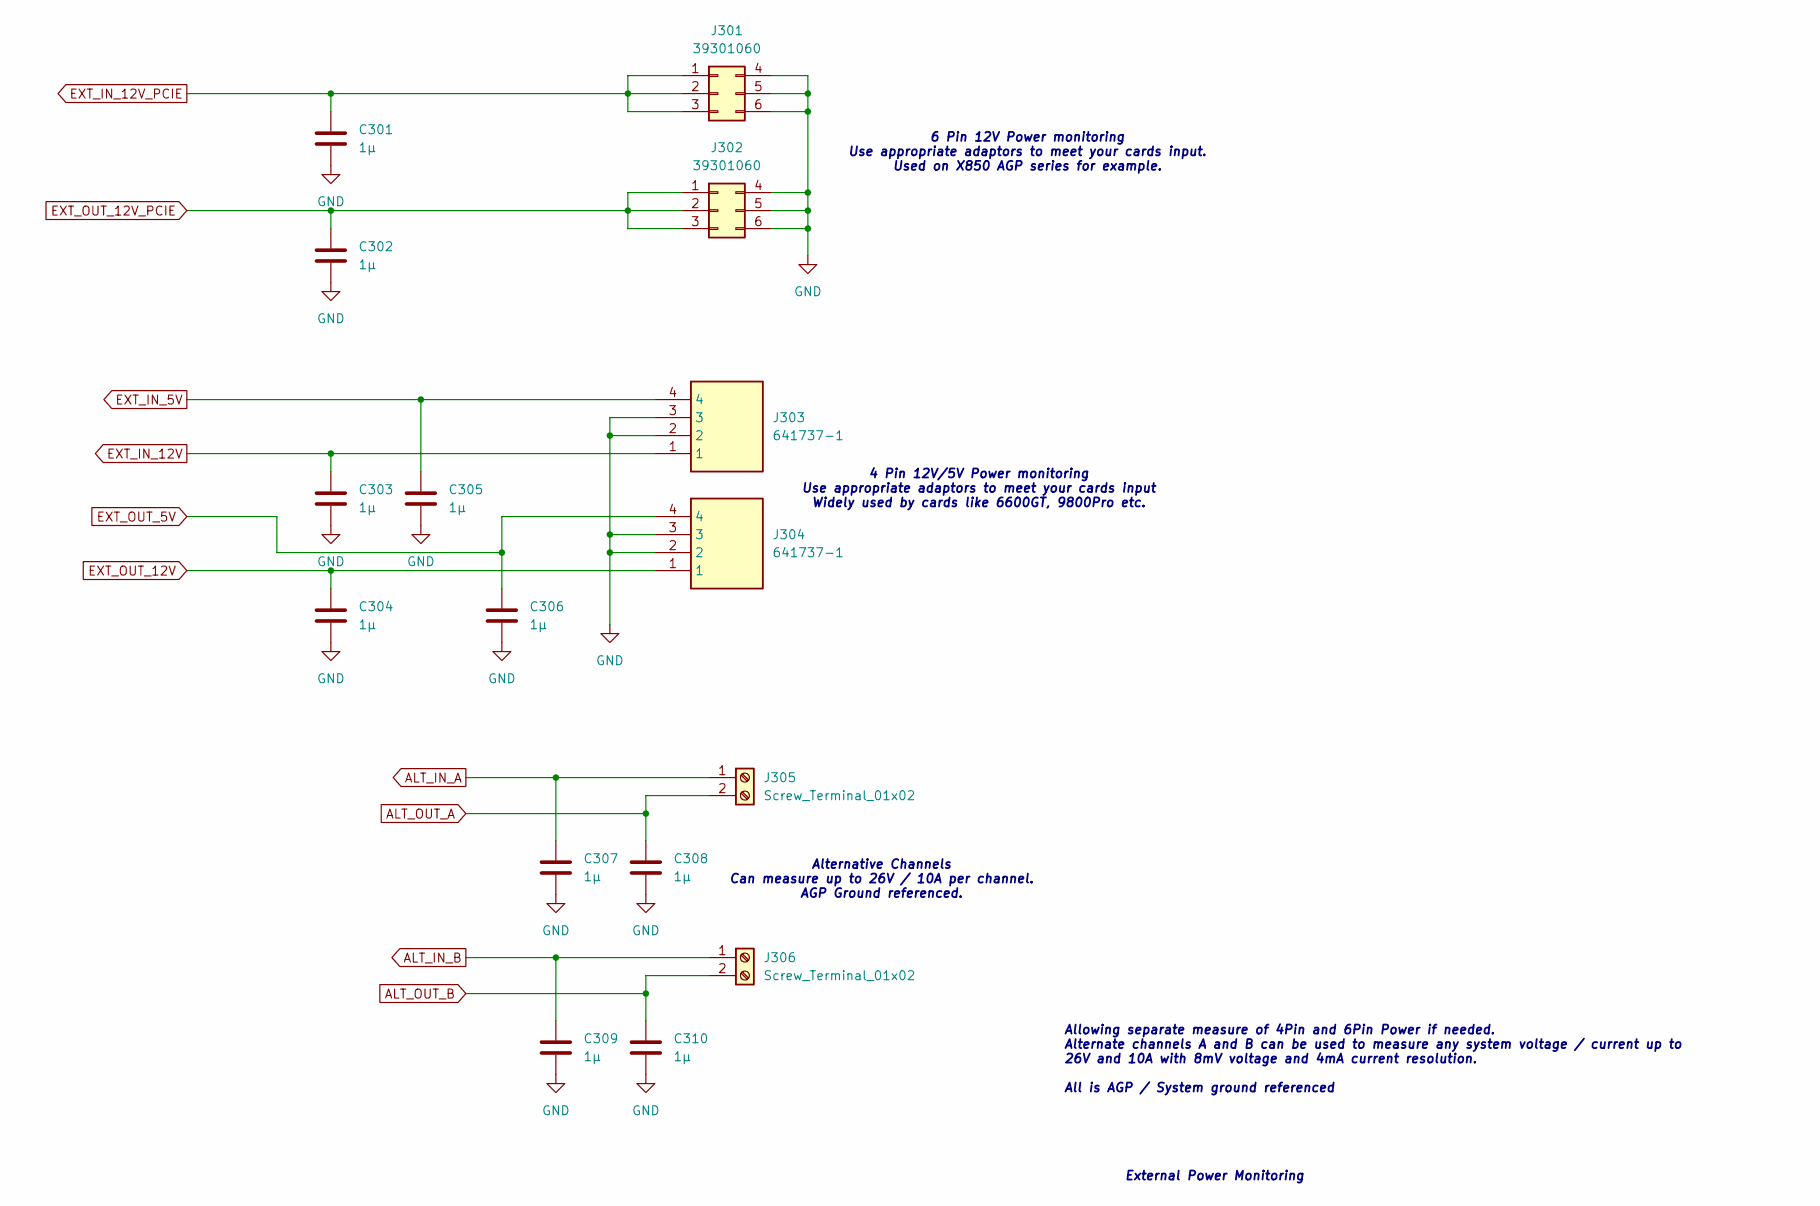
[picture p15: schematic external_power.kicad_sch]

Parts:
C301, C302, C303, C304, C305, C306, C307, C308, C309, C310: 1µ; C_0603_1608Metric
J301, J302: 39301060; Molex_Mini-Fit_Jr_5569-06A2_2x03_P4.20mm_Horizontal
J303, J304: 641737-1; Mouser Part Number 571-6417371
J305, J306: Screw_Terminal_01x02; TerminalBlock_RND_205-00232_1x02_P5.08mm_Horizontal

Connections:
ALT_IN_A: C307.1, J305.1; also elsewhere on the board
ALT_IN_B: C309.1, J306.1; also elsewhere on the board
ALT_OUT_A: C308.1, J305.2; also elsewhere on the board
ALT_OUT_B: C310.1, J306.2; also elsewhere on the board
EXT_IN_5V: C305.1, J303.4; also elsewhere on the board
EXT_IN_12V: C303.1, J303.1; also elsewhere on the board
EXT_IN_12V_PCIE: C301.1, J301.1, J301.2, J301.3; also elsewhere on the board
EXT_OUT_5V: C306.1, J304.4; also elsewhere on the board
EXT_OUT_12V: C304.1, J304.1; also elsewhere on the board
EXT_OUT_12V_PCIE: C302.1, J302.1, J302.2, J302.3; also elsewhere on the board
GND: C301.2, C302.2, C303.2, C304.2, C305.2, C306.2, C307.2, C308.2, C309.2, C310.2, J301.4, J301.5, J301.6, J302.4, J302.5, J302.6, J303.2, J303.3, J304.2, J304.3; also elsewhere on the board

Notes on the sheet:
Allowing separate measure of 4Pin and 6Pin Power if needed. Alternate channels A and B can be used to measure any system voltage / current up to 26V and 10A with 8mV voltage and 4mA current resolution. All is AGP / System ground referenced
Alternative Channels Can measure up to 26V / 10A per channel. AGP Ground referenced.
6 Pin 12V Power monitoring Use appropriate adaptors to meet your cards input. Used on X850 AGP series for example.
External Power Monitoring
4 Pin 12V/5V Power monitoring Use appropriate adaptors to meet your cards input Widely used by cards like 6600GT, 9800Pro etc.

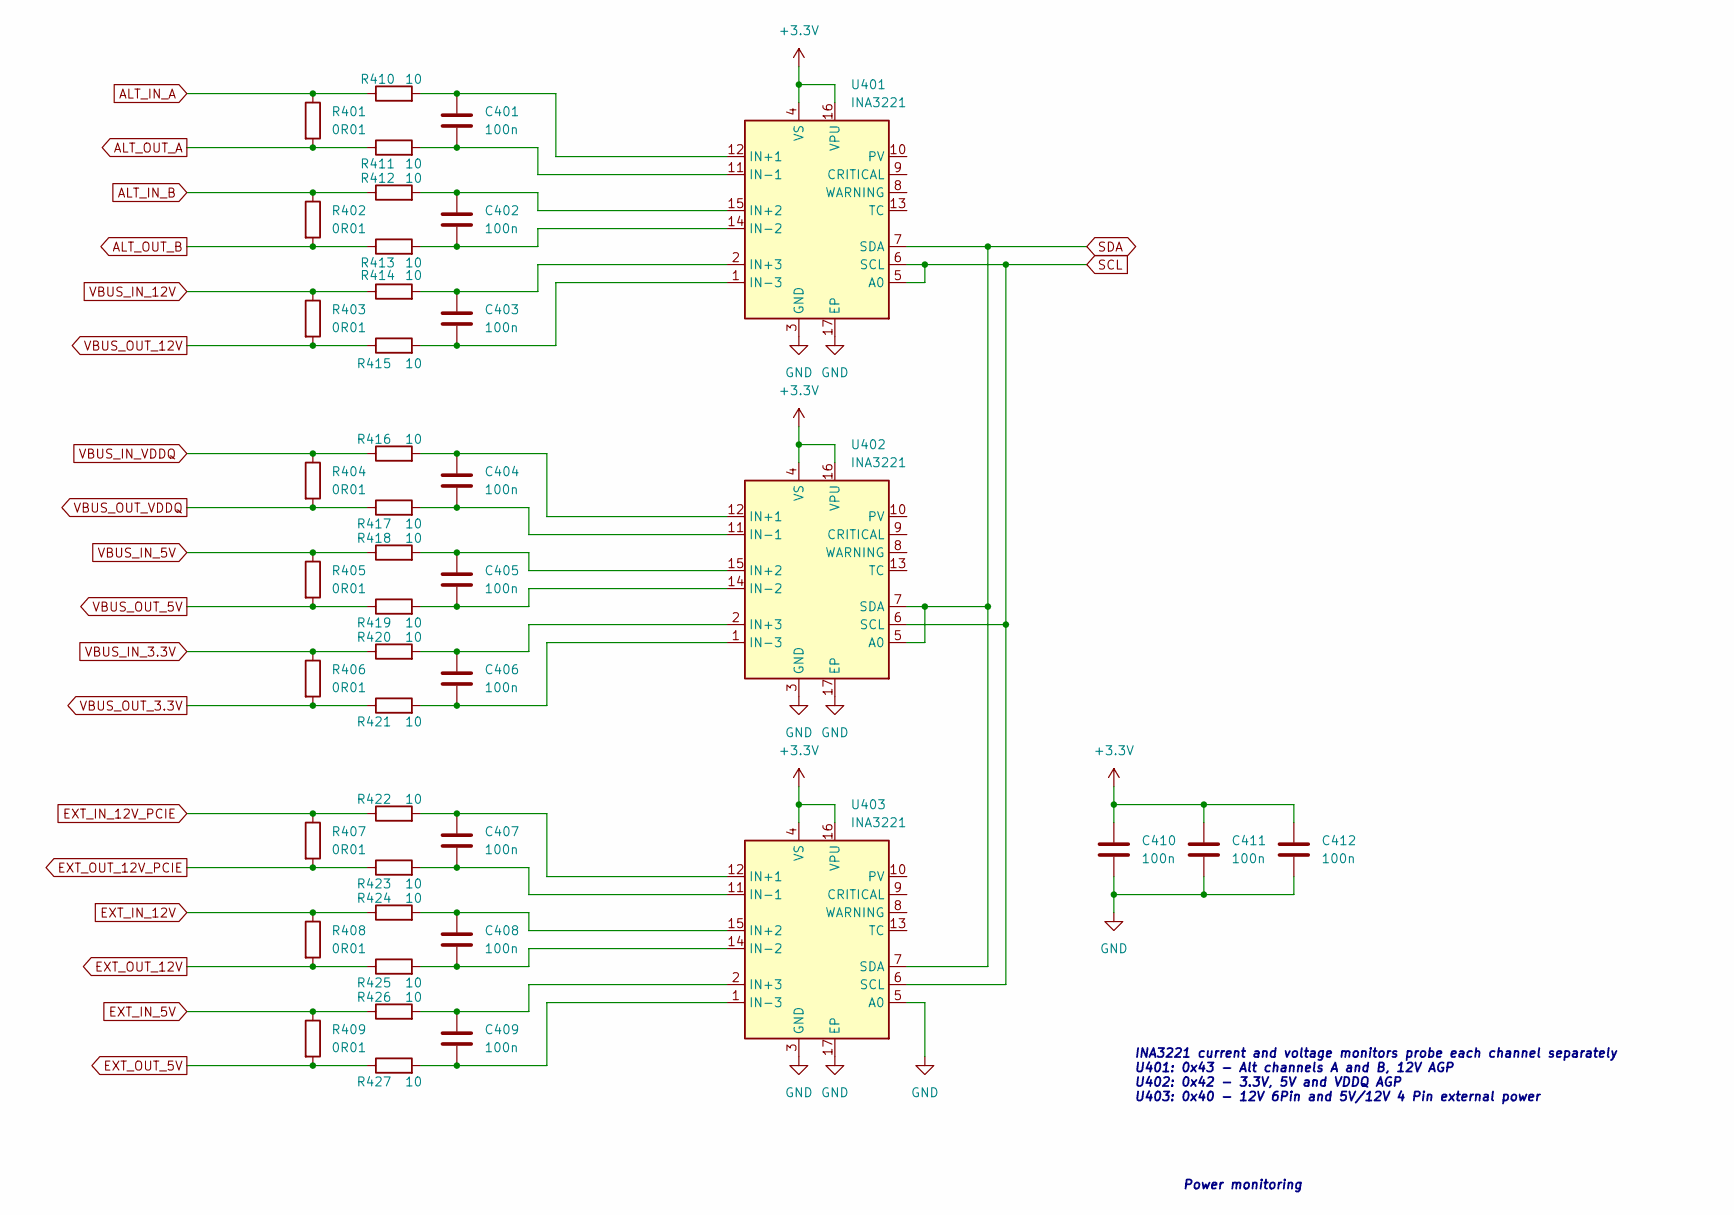
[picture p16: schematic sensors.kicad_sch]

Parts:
C401, C402, C403, C404, C405, C406, C407, C408, C409, C410, C411, C412: 100n; C_0603_1608Metric
R401, R402, R403, R404, R405, R406, R407, R408, R409: 0R01; R_2816_7142Metric
R410, R411, R412, R413, R414, R415, R416, R417, R418, R419, R420, R421, R422, R423, R424, R425, R426, R427: 10; R_0603_1608Metric
U401, U402, U403: INA3221; Texas_RGV0016A_VQFN-16-1EP_4x4mm_P0.65mm_EP2.1x2.1mm

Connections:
+3.3V: C410.1, C411.1, C412.1, U401.4 (VS), U401.16 (VPU), U402.4 (VS), U402.16 (VPU), U403.4 (VS), U403.16 (VPU); also elsewhere on the board
ALT_IN_A: R401.1, R410.1; also elsewhere on the board
ALT_IN_B: R402.1, R412.1; also elsewhere on the board
ALT_OUT_A: R401.2, R411.1; also elsewhere on the board
ALT_OUT_B: R402.2, R413.1; also elsewhere on the board
EXT_IN_5V: R409.1, R426.1; also elsewhere on the board
EXT_IN_12V: R408.1, R424.1; also elsewhere on the board
EXT_IN_12V_PCIE: R407.1, R422.1; also elsewhere on the board
EXT_OUT_5V: R409.2, R427.1; also elsewhere on the board
EXT_OUT_12V: R408.2, R425.1; also elsewhere on the board
EXT_OUT_12V_PCIE: R407.2, R423.1; also elsewhere on the board
GND: C410.2, C411.2, C412.2, U401.3 (GND), U401.17 (EP), U402.3 (GND), U402.17 (EP), U403.3 (GND), U403.5 (A0), U403.17 (EP); also elsewhere on the board
unnamed: C401.1, R410.2, U401.12 (IN+1)
unnamed: C402.1, R412.2, U401.15 (IN+2)
unnamed: C403.1, R414.2, U401.2 (IN+3)
unnamed: C401.2, R411.2, U401.11 (IN-1)
unnamed: C402.2, R413.2, U401.14 (IN-2)
unnamed: C403.2, R415.2, U401.1 (IN-3)
unnamed: C404.1, R416.2, U402.12 (IN+1)
unnamed: C405.1, R418.2, U402.15 (IN+2)
unnamed: C406.1, R420.2, U402.2 (IN+3)
unnamed: C404.2, R417.2, U402.11 (IN-1)
unnamed: C405.2, R419.2, U402.14 (IN-2)
unnamed: C406.2, R421.2, U402.1 (IN-3)
unnamed: C407.1, R422.2, U403.12 (IN+1)
unnamed: C408.1, R424.2, U403.15 (IN+2)
unnamed: C409.1, R426.2, U403.2 (IN+3)
unnamed: C407.2, R423.2, U403.11 (IN-1)
unnamed: C408.2, R425.2, U403.14 (IN-2)
unnamed: C409.2, R427.2, U403.1 (IN-3)
SCL: U401.5 (A0), U401.6 (SCL), U402.6 (SCL), U403.6 (SCL); also elsewhere on the board
SDA: U401.7 (SDA), U402.5 (A0), U402.7 (SDA), U403.7 (SDA); also elsewhere on the board
VBUS_IN_3.3V: R406.1, R420.1; also elsewhere on the board
VBUS_IN_5V: R405.1, R418.1; also elsewhere on the board
VBUS_IN_12V: R403.1, R414.1; also elsewhere on the board
VBUS_IN_VDDQ: R404.1, R416.1; also elsewhere on the board
VBUS_OUT_3.3V: R406.2, R421.1; also elsewhere on the board
VBUS_OUT_5V: R405.2, R419.1; also elsewhere on the board
VBUS_OUT_12V: R403.2, R415.1; also elsewhere on the board
VBUS_OUT_VDDQ: R404.2, R417.1; also elsewhere on the board

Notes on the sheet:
INA3221 current and voltage monitors probe each channel separately U401: 0x43 - Alt channels A and B, 12V AGP U402: 0x42 - 3.3V, 5V and VDDQ AGP U403: 0x40 - 12V 6Pin and 5V/12V 4 Pin external power
Power monitoring

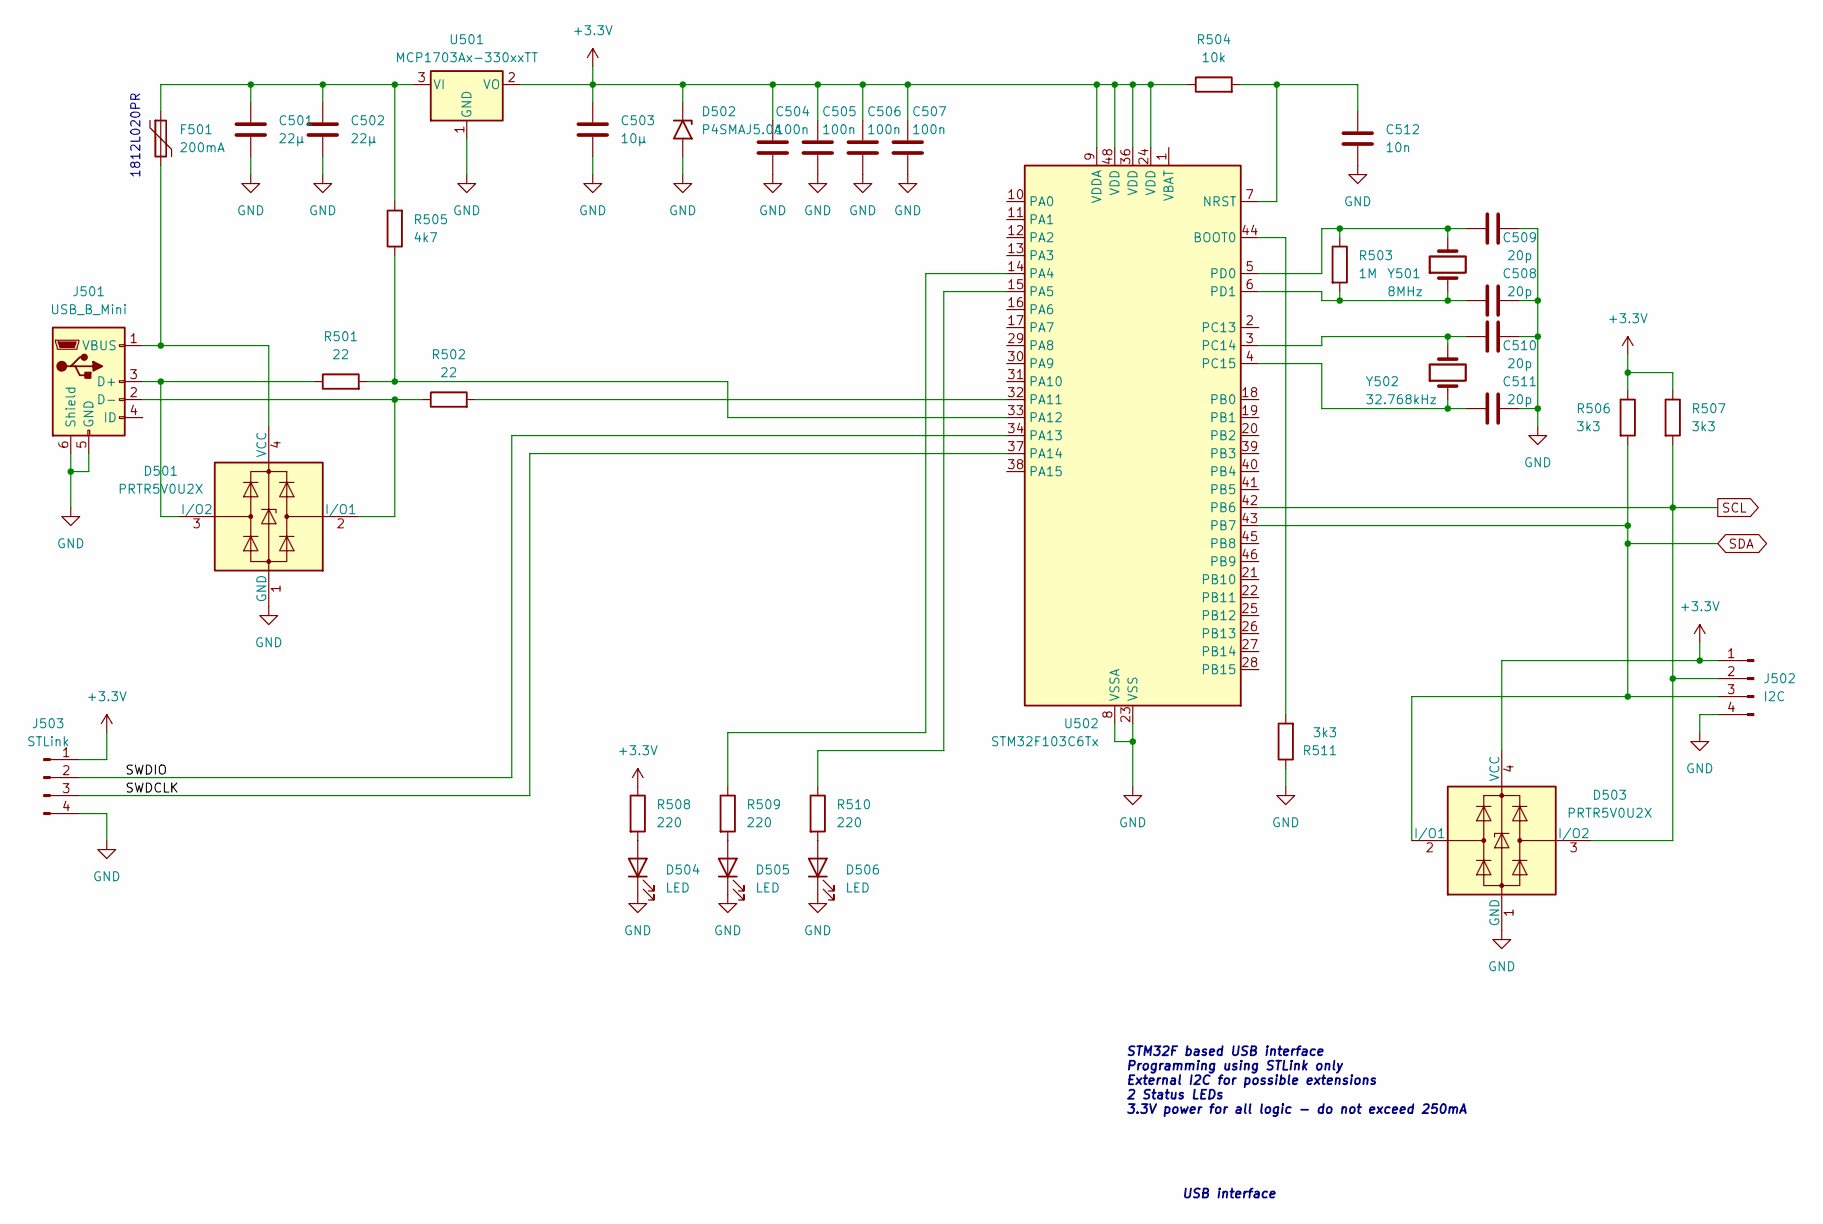
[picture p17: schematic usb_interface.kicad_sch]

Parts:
C501, C502: 22µ; C_1206_3216Metric
C503: 10µ; C_1206_3216Metric
C504, C505, C506, C507: 100n; C_0603_1608Metric
C508, C509, C510, C511: 20p; C_0603_1608Metric
C512: 10n; C_0603_1608Metric
D501, D503: PRTR5V0U2X; SOT-143
D502: P4SMAJ5.0A; D_SMA
D504, D505, D506: LED; LED_1206_3216Metric
F501: 200mA; Fuse_1812_4532Metric
J501: USB_B_Mini; USB_Mini-B_Wuerth_65100516121_Horizontal
J502: I2C; PinHeader_1x04_P2.54mm_Vertical
J503: STLink; PinHeader_1x04_P2.54mm_Vertical
R501, R502: 22; R_0603_1608Metric
R503: 1M; R_0603_1608Metric
R504: 10k; R_0603_1608Metric
R505: 4k7; R_0603_1608Metric
R506, R507, R511: 3k3; R_0603_1608Metric
R508, R509, R510: 220; R_0603_1608Metric
U501: MCP1703Ax-330xxTT; SOT-23
U502: STM32F103C6Tx; LQFP-48_7x7mm_P0.5mm
Y501: 8MHz; Crystal_HC49-U_Vertical
Y502: 32.768kHz; Crystal_DS10_D1.0mm_L4.3mm_Horizontal

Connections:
+3.3V: C503.1, C504.1, C505.1, C506.1, C507.1, D502.1 (A1), D503.4 (VCC), J502.1, J503.1, R504.1, R506.1, R507.1, R508.1, U501.2 (VO), U502.9 (VDDA), U502.24 (VDD), U502.36 (VDD), U502.48 (VDD); also elsewhere on the board
/usb_interface/SWDCLK: J503.3, U502.37 (PA14)
/usb_interface/SWDIO: J503.2, U502.34 (PA13)
GND: C501.2, C502.2, C503.2, C504.2, C505.2, C506.2, C507.2, C508.2, C509.2, C510.2, C511.2, C512.2, D501.1 (GND), D502.2 (A2), D503.1 (GND), D504.1 (K), D505.1 (K), D506.1 (K), J501.5 (GND), J501.6 (Shield), J502.4, J503.4, R511.1, U501.1 (GND), U502.8 (VSSA), U502.23 (VSS), U502.35 (VSS), U502.47 (VSS); also elsewhere on the board
unnamed: D501.2 (I/O1), J501.2 (D-), R502.1
unnamed: D501.3 (I/O2), J501.3 (D+), R501.1
unnamed: D501.4 (VCC), F501.2, J501.1 (VBUS)
unnamed: D504.2 (A), R508.2
unnamed: D505.2 (A), R509.2
unnamed: D506.2 (A), R510.2
unnamed: C501.1, C502.1, F501.1, R505.2, U501.3 (VI)
unnamed: R511.2, U502.44 (BOOT0)
unnamed: C512.1, R504.2, U502.7 (NRST)
unnamed: R509.1, U502.14 (PA4)
unnamed: R510.1, U502.15 (PA5)
unnamed: R502.2, U502.32 (PA11)
unnamed: R501.2, R505.1, U502.33 (PA12)
unnamed: C510.1, U502.3 (PC14), Y502.2
unnamed: C511.1, U502.4 (PC15), Y502.1
unnamed: C509.1, R503.1, U502.5 (PD0), Y501.2
unnamed: C508.1, R503.2, U502.6 (PD1), Y501.1
SCL: D503.3 (I/O2), J502.2, R507.2, U502.42 (PB6); also elsewhere on the board
SDA: D503.2 (I/O1), J502.3, R506.2, U502.43 (PB7); also elsewhere on the board

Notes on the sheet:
USB interface
STM32F based USB interface Programming using STLink only External I2C for possible extensions 2 Status LEDs 3.3V power for all logic - do not exceed 250mA
1812L020PR

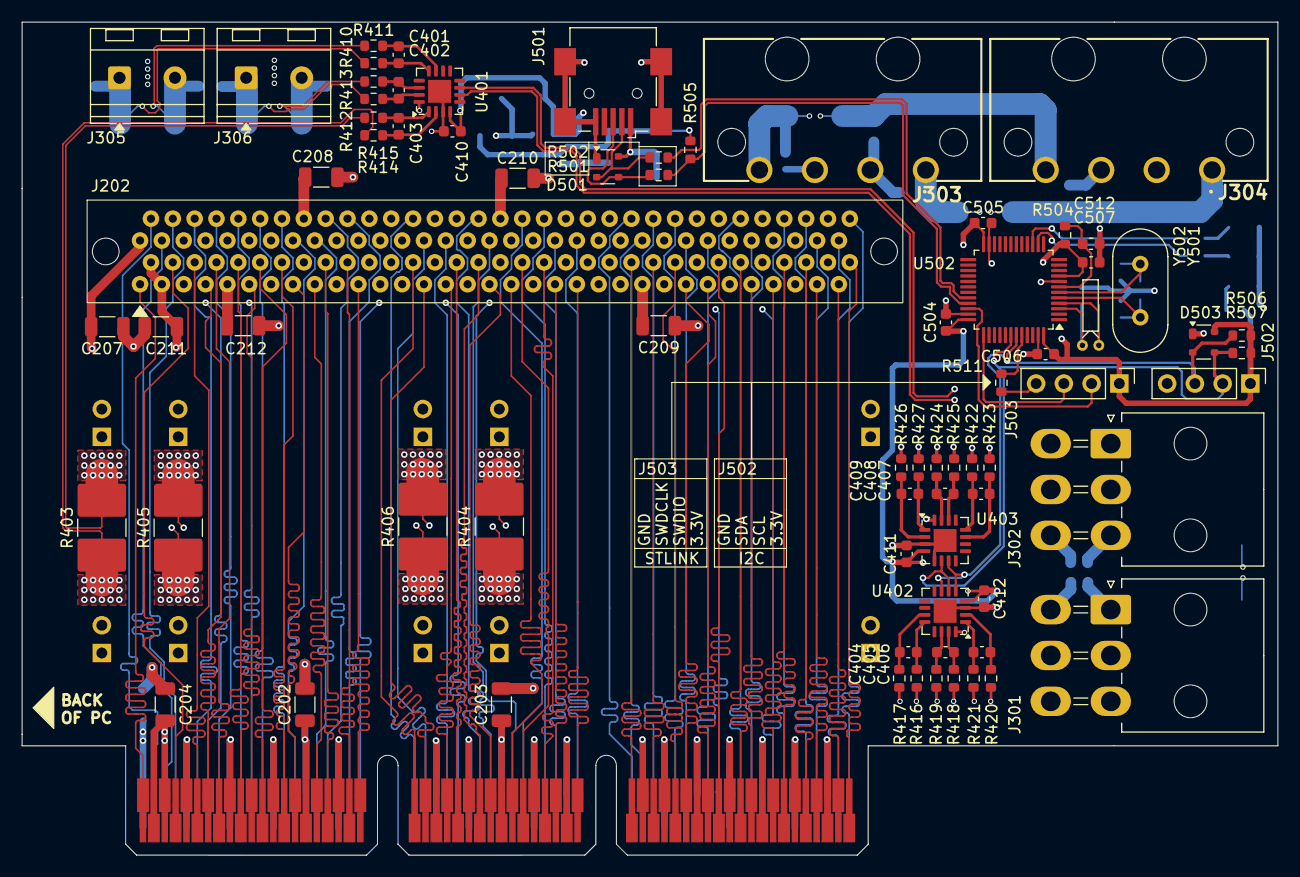
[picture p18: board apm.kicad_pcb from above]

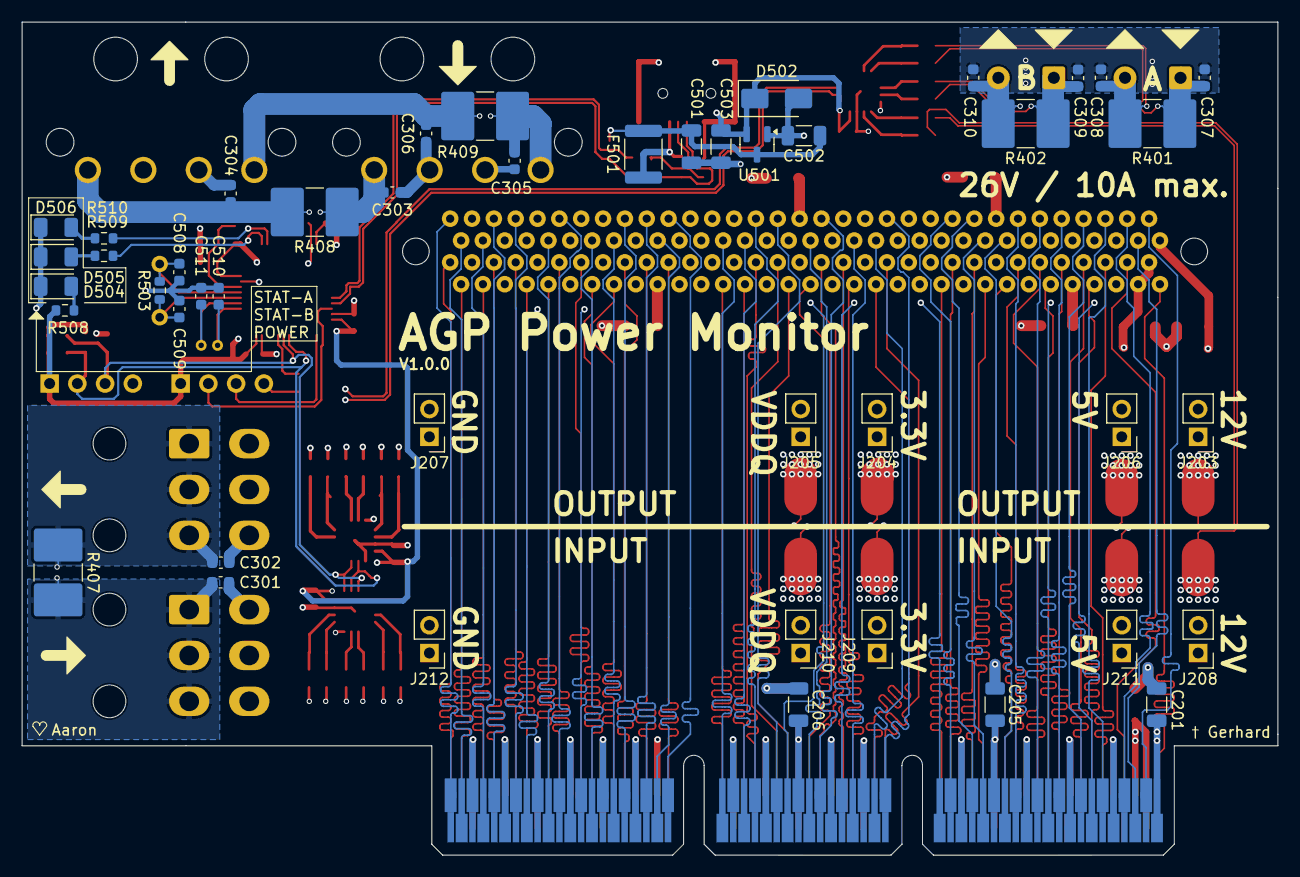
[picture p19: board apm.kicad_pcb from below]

Board: 4 copper layers, 115.0 x 76.3 mm, 119 parts (45 on the bottom side), 139 nets.

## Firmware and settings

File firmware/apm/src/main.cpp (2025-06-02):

#include <Arduino.h>
#include <Wire.h>
#include <STM32RTC.h>

// LEDs for status indication
#define STAT_A_LED PA4
#define STAT_B_LED PA5

// INA3221 I2C addresses
// U401 - rails: alternative channel A and B, 12V AGP
#define INA1_ADDRESS 0x43
// U402 - rails: 3.3V AGP, 5V AGP, VDDQ AGP
#define INA2_ADDRESS 0x42
// U403 - rails: 12V 6Pin, 5V 4Pin, 12V 4Pin
#define INA3_ADDRESS 0x40

// INA3221 register addresses
#define INA3221_REG_CONFIG         0x00
#define INA3221_REG_SHUNTVOLTAGE_1 0x01
#define INA3221_REG_BUSVOLTAGE_1   0x02
// Each channel is +2 from previous
#define INA3221_REG_SHUNTVOLTAGE_2 0x03
#define INA3221_REG_BUSVOLTAGE_2   0x04
#define INA3221_REG_SHUNTVOLTAGE_3 0x05
#define INA3221_REG_BUSVOLTAGE_3   0x06

// Serial command definitions
#define CMD_SET_RTC      'R'  // Set RTC: R<unix_timestamp>
#define CMD_START_SAMPLE 'S'  // Start sampling: S
#define CMD_STOP_SAMPLE  'P'  // Stop sampling: P

// Sampling control
bool samplingActive = false;
bool rtcConfigured = false;
unsigned long lastBlinkTime = 0;
const unsigned long blinkInterval = 500;

// RTC object
STM32RTC& rtc = STM32RTC::getInstance();
time_t previousSampleTime = 0;
int8_t sampleCount = 0;

// Command buffer
const int MAX_CMD_LENGTH = 32;
char cmdBuffer[MAX_CMD_LENGTH];
int cmdIndex = 0;

// CRC-16 (CCITT) calculation function
uint16_t crc16_ccitt(const uint8_t* data, size_t length) {
  uint16_t crc = 0xFFFF;
  for (size_t i = 0; i < length; i++) {
    crc ^= (uint16_t)data[i] << 8;
    for (uint8_t j = 0; j < 8; j++) {
      if (crc & 0x8000) crc = (crc << 1) ^ 0x1021;
      else crc <<= 1;
    }
  }
  return crc;
}

// Helper to write 16-bit register to INA3221
void writeINA3221Register(uint8_t address, uint8_t reg, uint16_t value) {
  Wire.beginTransmission(address);
  Wire.write(reg);
  Wire.write((value >> 8) & 0xFF);
  Wire.write(value & 0xFF);
  Wire.endTransmission();
}

// Helper to read 16-bit register from INA3221
uint16_t readINA3221Register(uint8_t address, uint8_t reg) {
  Wire.beginTransmission(address);
  Wire.write(reg);
  Wire.endTransmission(false);
  Wire.requestFrom(address, (uint8_t)2);
  uint16_t value = 0;
  if (Wire.available() == 2) {
    value = (Wire.read() << 8) | Wire.read();
  }
  return value;
}

// Initialize INA3221
void setupINA3221() {
  // Continuous mode, enable all channels, averaging 16 samples, using 1.1ms conversion time for both shunt and bus voltages
  // 15   14   13   12   11   10   9    8    7    6    5    4    3    2    1    0
  // RST  EN1  EN2  EN3  AV2  AV1  AV0  CB2  CB1  CB0  CS2  CS1  CS0  M3   M2   M1
  // 1    1    1    1    0    1    0    1    0    0    1    0    0    1    1    1
  // This sets the INA3221 to: 0b1111010101000111
  // This sets the INA3221 to: 0xF547
  writeINA3221Register(INA1_ADDRESS, INA3221_REG_CONFIG, 0xF547);
  writeINA3221Register(INA2_ADDRESS, INA3221_REG_CONFIG, 0xF547);
  writeINA3221Register(INA3_ADDRESS, INA3221_REG_CONFIG, 0xF547);
}

// Update LED status based on RTC configuration
void updateStatusLED() {
  if (!rtcConfigured) {
    // Blink STAT_A_LED if RTC is not configured
    if (millis() - lastBlinkTime >= blinkInterval) {
      lastBlinkTime = millis();
      digitalWrite(STAT_A_LED, !digitalRead(STAT_A_LED));
    }
  } else {
    // Solid LED if RTC is configured
    digitalWrite(STAT_A_LED, HIGH);
  }
}

// Process and take a sample
void takeSample() {
  // Read the current time from the RTC
  time_t currentSampleTime = rtc.getEpoch();

  // Check if the time has changed since the last sample
  if (currentSampleTime != previousSampleTime) {
    // Reset the sample counter for the new seconds we're running in
    sampleCount = 0;
  } else {
    // Increment the sample count
    sampleCount++;
  }
  // Update the previous sample time
  previousSampleTime = currentSampleTime;

  // Create a data buffer to accommodate 16-bit values
  uint8_t data[50];
  
  // Timestamp - 4 bytes (32 bits)
  // Store the current sample time in big-endian format
  data[0] = (currentSampleTime >> 24) & 0xFF;
  data[1] = (currentSampleTime >> 16) & 0xFF;
  data[2] = (currentSampleTime >> 8) & 0xFF;
  data[3] = currentSampleTime & 0xFF;
  
  // Sample count - 1 byte
  data[4] = sampleCount;
  
  // Process bus voltages (convert to mV as 16-bit values)
  // Each value takes 2 bytes (16 bits)
  int index = 5;

  // Function to store a 16-bit value in the data array,
  // The data is a signed 16-bit
  // Storing the high byte first, then the low byte (big-endian format)
  auto store16BitValue = [&data, &index](uint16_t value) {
    data[index++] = (value >> 8) & 0xFF; // High byte
    data[index++] = value & 0xFF;        // Low byte
  };

  // Store all bus voltages
  store16BitValue(readINA3221Register(INA1_ADDRESS, INA3221_REG_BUSVOLTAGE_1)); // Channel 1
  store16BitValue(readINA3221Register(INA1_ADDRESS, INA3221_REG_BUSVOLTAGE_2)); // Channel 2
  store16BitValue(readINA3221Register(INA1_ADDRESS, INA3221_REG_BUSVOLTAGE_3)); // Channel 3
  store16BitValue(readINA3221Register(INA2_ADDRESS, INA3221_REG_BUSVOLTAGE_1)); // Channel 1
  store16BitValue(readINA3221Register(INA2_ADDRESS, INA3221_REG_BUSVOLTAGE_2)); // Channel 2
  store16BitValue(readINA3221Register(INA2_ADDRESS, INA3221_REG_BUSVOLTAGE_3)); // Channel 3
  store16BitValue(readINA3221Register(INA3_ADDRESS, INA3221_REG_BUSVOLTAGE_1)); // Channel 1
  store16BitValue(readINA3221Register(INA3_ADDRESS, INA3221_REG_BUSVOLTAGE_2)); // Channel 2
  store16BitValue(readINA3221Register(INA3_ADDRESS, INA3221_REG_BUSVOLTAGE_3)); // Channel 3

  // Store all currents
  store16BitValue(readINA3221Register(INA1_ADDRESS, INA3221_REG_SHUNTVOLTAGE_1)); // Channel 1
  store16BitValue(readINA3221Register(INA1_ADDRESS, INA3221_REG_SHUNTVOLTAGE_2)); // Channel 2
  store16BitValue(readINA3221Register(INA1_ADDRESS, INA3221_REG_SHUNTVOLTAGE_3)); // Channel 3
  store16BitValue(readINA3221Register(INA2_ADDRESS, INA3221_REG_SHUNTVOLTAGE_1)); // Channel 1
  store16BitValue(readINA3221Register(INA2_ADDRESS, INA3221_REG_SHUNTVOLTAGE_2)); // Channel 2
  store16BitValue(readINA3221Register(INA2_ADDRESS, INA3221_REG_SHUNTVOLTAGE_3)); // Channel 3
  store16BitValue(readINA3221Register(INA3_ADDRESS, INA3221_REG_SHUNTVOLTAGE_1)); // Channel 1
  store16BitValue(readINA3221Register(INA3_ADDRESS, INA3221_REG_SHUNTVOLTAGE_2)); // Channel 2
  store16BitValue(readINA3221Register(INA3_ADDRESS, INA3221_REG_SHUNTVOLTAGE_3)); // Channel 3

  // Calculate CRC-16 (CCITT) for the data packet
  uint16_t crc = crc16_ccitt(data, index);
  // Store the CRC-16 in the data packet
  data[index++] = (crc >> 8) & 0xFF; // High byte
  data[index++] = crc & 0xFF;        // Low byte

  // Add a FF0033 to the end of the data packet
  data[index++] = 0xFF;
  data[index++] = 0x00;
  data[index++] = 0x33;

  // Write the data to the serial port
  Serial.write(data, index);

  // Toggle the STAT_B_LED to indicate sampling activity
  if (sampleCount == 0) {
    digitalWrite(STAT_B_LED, !digitalRead(STAT_B_LED));
  }
}

// Process a complete command
void processCommand(char* cmd) {
  if (cmd[0] == CMD_SET_RTC) {
    // Only allow RTC setting if not currently sampling
    if (!samplingActive) {
      // Parse the timestamp from the command string
      time_t newTime = strtoul(&cmd[1], NULL, 10);
      if (newTime > 1609459200) { // Sanity check: after Jan 1, 2021
        rtc.setEpoch(newTime);
        rtcConfigured = true;
        Serial.println("RTC set");
      } else {
        Serial.println("Invalid timestamp");
      }
    } else {
      Serial.println("Stop sampling first");
    }
  } 
  else if (cmd[0] == CMD_START_SAMPLE) {
    if (rtcConfigured) {
      samplingActive = true;
      Serial.println("Sampling started");
    } else {
      Serial.println("Configure RTC first");
    }
  } 
  else if (cmd[0] == CMD_STOP_SAMPLE) {
    samplingActive = false;
    Serial.println("Sampling stopped");
  } 
}

// Process incoming serial data for commands
void handleSerial() {
  while (Serial.available() > 0) {
    char inChar = (char)Serial.read();
    
    // If newline or carriage return, process the command
    if (inChar == '\n' || inChar == '\r') {
      if (cmdIndex > 0) {
        cmdBuffer[cmdIndex] = '\0';
        processCommand(cmdBuffer);
        cmdIndex = 0;
      }
    } 
    // Otherwise add to buffer if not full
    else if (cmdIndex < MAX_CMD_LENGTH - 1) {
      cmdBuffer[cmdIndex++] = inChar;
    }
  }
}

void setup() {
  // Initialize serial communication, baud rate does not matter, since we're running over USB
  Serial.begin(115200);
  // Set the LED pins as outputs
  pinMode(STAT_A_LED, OUTPUT);
  pinMode(STAT_B_LED, OUTPUT);
  // Set the LED pins to LOW to turn them off
  digitalWrite(STAT_A_LED, LOW);
  digitalWrite(STAT_B_LED, LOW);

  // Initialize the I2C bus
  Wire.begin();
  // Set the I2C bus frequency to 400kHz
  Wire.setClock(400000);

  // Initialize the RTC
  rtc.begin(true, STM32RTC::HOUR_24);

  // Run initialization for INA3221
  setupINA3221();
}

void loop() {
  // Update the LED status based on RTC configuration
  updateStatusLED();
  
  // Handle incoming serial commands
  handleSerial();
  
  // If sampling is active, take a sample
  if (samplingActive && rtcConfigured) {
    takeSample();
  }
}

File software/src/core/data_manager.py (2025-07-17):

#!/usr/bin/env python3
# AGP Power Monitor
# Copyright (C) 2025 - tehsiggi

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
import csv
from collections import deque
import time
import sys
from typing import Dict, List, Any

class DataManager:
    """
    Buffer manager for rail voltage, current and power data.
    Maintains statistics (average, min, max) for all values.
    Also manages connection and sampling status.
    """
    
    def __init__(self, max_buffer_size_mb: float = 100.0, config_manager=None):
        """
        Initialize the data manager with a configurable buffer size.
        
        Args:
            max_buffer_size_mb: Maximum buffer size in megabytes
            config_manager: Optional ConfigManager instance for centralized settings
        """
        self.NUM_RAILS = 9
        self.config_manager = config_manager
        
        # Get buffer size from config manager if available
        if config_manager:
            max_buffer_size_mb = config_manager.get("measurement.maxBufferSizeMB", max_buffer_size_mb)
            # Register callback for buffer size changes
            config_manager.register_callback("measurement.maxBufferSizeMB", self._on_buffer_size_changed)
            
        self.max_buffer_size_bytes = int(max_buffer_size_mb * 1024 * 1024)
        self.data_buffer = deque()
        
        # Connection and sampling state
        self.is_connected = False
        self.is_sampling = False
        
        # Tracking insert rate
        self.insert_times = deque(maxlen=1000)  # Track last 1000 inserts for rate calculation
        
        # Statistics for each rail
        self.stats = {
            'voltage': {'avg': [0] * self.NUM_RAILS, 'min': [float('inf')] * self.NUM_RAILS, 'max': [float('-inf')] * self.NUM_RAILS},
            'current': {'avg': [0] * self.NUM_RAILS, 'min': [float('inf')] * self.NUM_RAILS, 'max': [float('-inf')] * self.NUM_RAILS},
            'power': {'avg': [0] * self.NUM_RAILS, 'min': [float('inf')] * self.NUM_RAILS, 'max': [float('-inf')] * self.NUM_RAILS}
        }
        
        # Running sums for average calculation
        self._sums = {
            'voltage': [0] * self.NUM_RAILS,
            'current': [0] * self.NUM_RAILS,
            'power': [0] * self.NUM_RAILS
        }
        self.total_entries = 0
    
    def get_buffer_size_bytes(self) -> int:
        """Get the current buffer size in bytes"""
        # Estimate size of the buffer using sys.getsizeof
        return sum(sys.getsizeof(item) for item in self.data_buffer)
    
    def get_buffer_size_mb(self) -> float:
        """Get the current buffer size in megabytes"""
        return self.get_buffer_size_bytes() / (1024 * 1024)
    
    def get_max_buffer_size_mb(self) -> float:
        """Get the maximum buffer size in megabytes"""
        return self.max_buffer_size_bytes / (1024 * 1024)
    
    def set_max_buffer_size_mb(self, max_buffer_size_mb: float) -> None:
        """Set the maximum buffer size in megabytes"""
        self.max_buffer_size_bytes = int(max_buffer_size_mb * 1024 * 1024)
        # Trim buffer if needed
        self._trim_buffer_if_needed()
        
        # Update setting in config manager if available
        if self.config_manager:
            # This will avoid recursion since we don't update max_buffer_size_bytes 
            # if it's the same value
            self.config_manager.set("measurement.maxBufferSizeMB", max_buffer_size_mb)
            
    def _on_buffer_size_changed(self, key, new_value, old_value):
        """
        Callback for when buffer size setting changes in config manager
        
        Args:
            key: The setting key (always "measurement.maxBufferSizeMB")
            new_value: New buffer size in MB
            old_value: Previous buffer size in MB
        """
        if new_value != old_value:
            # Update buffer size in bytes
            self.max_buffer_size_bytes = int(new_value * 1024 * 1024)
            # Trim buffer if needed
            self._trim_buffer_if_needed()
    
    def _trim_buffer_if_needed(self) -> None:
        """Remove oldest entries if buffer exceeds max size"""
        current_size = self.get_buffer_size_bytes()
        while current_size > self.max_buffer_size_bytes and self.data_buffer:
            # Remove oldest entry
            removed_entry = self.data_buffer.popleft()
            
            # Update statistics when removing entries
            if self.total_entries > 0:
                self.total_entries -= 1
                
                # Update sums for removed entry
                for rail_idx in range(self.NUM_RAILS):
                    self._sums['voltage'][rail_idx] -= removed_entry['voltage'][rail_idx]
                    self._sums['current'][rail_idx] -= removed_entry['current'][rail_idx]
                    self._sums['power'][rail_idx] -= removed_entry['power'][rail_idx]
                
                # Recalculate averages if we still have data
                if self.total_entries > 0:
                    self._recalculate_stats()
                else:
                    # Reset stats if buffer is empty
                    self._reset_stats()
            
            current_size = self.get_buffer_size_bytes()
    
    def _reset_stats(self) -> None:
        """Reset statistics when buffer is empty"""
        for metric in ['voltage', 'current', 'power']:
            self.stats[metric]['avg'] = [0] * self.NUM_RAILS
            self.stats[metric]['min'] = [float('inf')] * self.NUM_RAILS
            self.stats[metric]['max'] = [float('-inf')] * self.NUM_RAILS
            self._sums[metric] = [0] * self.NUM_RAILS
    
    def _recalculate_stats(self) -> None:
        """Recalculate min, max values by scanning the entire buffer"""
        # This is called when entries are removed and we need to ensure min/max are accurate
        if not self.data_buffer:
            self._reset_stats()
            return
            
        # Reset min/max
        for metric in ['voltage', 'current', 'power']:
            self.stats[metric]['min'] = [float('inf')] * self.NUM_RAILS
            self.stats[metric]['max'] = [float('-inf')] * self.NUM_RAILS
        
        # Scan buffer for new min/max
        for entry in self.data_buffer:
            for rail_idx in range(self.NUM_RAILS):
                for metric in ['voltage', 'current', 'power']:
                    value = entry[metric][rail_idx]
                    self.stats[metric]['min'][rail_idx] = min(self.stats[metric]['min'][rail_idx], value)
                    self.stats[metric]['max'][rail_idx] = max(self.stats[metric]['max'][rail_idx], value)
        
        # Update averages
        for metric in ['voltage', 'current', 'power']:
            for rail_idx in range(self.NUM_RAILS):
                self.stats[metric]['avg'][rail_idx] = self._sums[metric][rail_idx] / self.total_entries if self.total_entries > 0 else 0
    
    def insert_data(self, voltages: List[float], currents: List[float]) -> None:
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

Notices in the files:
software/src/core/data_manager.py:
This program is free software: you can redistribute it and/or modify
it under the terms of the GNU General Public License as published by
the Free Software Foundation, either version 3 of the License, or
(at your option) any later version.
